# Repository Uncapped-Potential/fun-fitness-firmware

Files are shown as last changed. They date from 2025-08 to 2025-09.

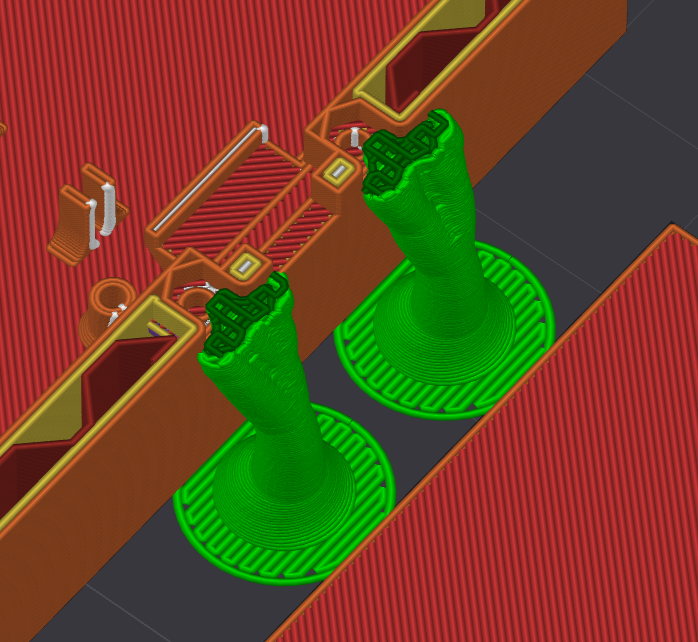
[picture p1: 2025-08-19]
enclosure_3D_models/print orientation photos and settings/cross section - not full depth supports.png

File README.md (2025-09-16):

# Fun Fitness Firmware

Production-ready ESP32-C3 firmware for the Fun Fitness wireless game controller with high-performance motion tracking and OTA update support.

## 🚀 Production Firmware

**Main firmware location**: [`codecell-firmware-minimal/`](./codecell-firmware-minimal/)

This is the production-ready firmware with:
- **60Hz Performance** - A:60Hz G:60Hz Q:20-40Hz BLE:60Hz streaming
- **Modular Architecture** - Clean separation with IMU manager and OTA worker
- **OTA Ready** - Complete over-the-air update implementation
- **Real Battery Status** - Proper USB/charging detection for OTA authorization

## Features

- **9-axis IMU** - Real-time motion tracking (accelerometer, gyroscope, rotation, magnetometer)
- **BLE Communication** - 60Hz quaternion streaming with 19-byte binary protocol
- **Motion Detection** - Configurable threshold with LED feedback
- **Power Management** - Vendor-compliant sleep/wake with motion-based activation
- **OTA Updates** - Queue-based firmware updates with CRC32 validation

## Hardware

- **Board**: CodeCell ESP32-C3
- **Sensors**: Built-in 9-axis IMU with magnetometer
- **Communication**: Bluetooth Low Energy (BLE)
- **Power**: Battery with USB charging

## 📁 Repository Structure

- **[`codecell-firmware-minimal/`](./codecell-firmware-minimal/)** - Production firmware (USE THIS)
- **[`archive/`](./archive/)** - Previous firmware experiments and troubleshooting docs
- **[`enclosure_3D_models/`](./enclosure_3D_models/)** - 3D printable enclosure files

## 🏗️ Development History

All previous firmware experiments have been archived to keep the repository clean. The current production firmware represents the culmination of extensive performance optimization and feature development, achieving reliable 60Hz streaming performance with proper power management.

## Bill of Materials (BOM)

### Core Components

1. **CodeCell Light + Motion (170mAh battery)**
   - Product: [CodeCell from Microbots.io](https://microbots.io/products/codecell)
   - Variant: Light + Motion / 170mAh 20C LiPo / Unsoldered
   - Specifications:
     - ESP32-C3 32-bit RISC-V (160 MHz)
     - BNO085 9-axis IMU (accelerometer, gyroscope, magnetometer)
     - VCNL4040 light/proximity sensor
     - 170mAh LiPo battery included
     - Dimensions: 18.5 x 18.5 x 9.4 mm
   - Included: 4x M1.2 self-tapping screws (~5mm) for mounting

2. **Power Switch**
   - Product: [SPDT Mini Slide Switch](https://www.amazon.com/dp/B0DN69PJ43)
   - Specifications:
     - Model: SS12D00G
     - Size: 8.7 x 3.7 x 11.7mm (L x W x H)
     - Pin Pitch: 0.1" / 2.54mm
     - Type: SPDT on-off, 3 pins
     - Mounting: Vertical through-hole, panel mount
     - Sliding knob length: 3mm
   - Quantity needed: 1

### Connectors and Cables

3. **JST 1.25mm Connectors**
   - Product: [JST 1.25mm 2-Pin Male/Female Cables](https://www.amazon.com/dp/B013JRWCBU)
   - Use: Battery connection
   - Quantity needed: 1 male-female pair

4. **USB-C Cable**
   - Product: [USB-C to USB-C Cable](https://www.amazon.com/dp/B0CGNK4LTT) (or any USB-C cable)
   - Use: Programming and charging
   - Quantity needed: 1

### Mounting Hardware

5. **M1.2 x 0.25mm Screws** (Current Option)
   - Product: [Laptop Screw Set](https://www.amazon.com/dp/B0D8PMBPB7)
   - Specifications: M1.2 x 0.25mm thread pitch, 4-6mm length
   - Quantity needed: 2 screws (from set)
   - Note: Currently tested and supported

6. **M1.2 x 0.25mm Nuts** (Current Option)
   - Product: [Stainless Steel Screw Set](https://www.amazon.com/dp/B0DBHNJLTD)
   - Specifications: M1.2 x 0.25mm thread pitch
   - Quantity needed: 2 nuts (from set)
   - Note: Must be press-fit into enclosure holes

**Alternative Hardware (Future - Testing in Progress):**
- **Screws**: [M1.2 x 5mm Individual Screws](https://www.amazon.com/dp/B0C1S9GHVB) - Specific size option
- **Nuts**: [M1.2 Hex Nuts](https://www.amazon.com/dp/B01N8UF3HU) - Individual nuts
- Note: These alternatives are being tested but not yet fully validated

7. **Mounting Adhesive**
   - Product: [Command Strips Velcro](https://www.amazon.com/dp/B0B3SR5M71) or any adhesive velcro
   - Use: Mounting controller to surfaces
   - Quantity needed: As required

### 3D Printed Enclosure

8. **Enclosure Components** (see `/enclosure_3D_models` directory)
   - **Files**: 
     - Up_FF_Body_V9_Rev_4.3mf (Body)
     - UP_FF_Lid_V9_Rev_4.3mf (Lid)
   - **Material**: **FIRE RETARDANT (PC-FR) REQUIRED** for production use
   - **Quantity**: 1 of each component
   - **Format**: 3MF files provided, Bambu print profile available (may need adjustment for Prusa A1)
   - **Note**: Standard materials acceptable for internal testing only

#### Print Settings
   - **Layer Height**: 0.12mm
   - **Infill**: 15%
   - **Wall Loops**: 2
   - **Supports**: Minimal - CRITICAL: Only add supports to outer perimeter of holes
   - **Orientation**: See photos in `/enclosure_3D_models/print orientation photos and settings/`
   - **Important**: Do NOT add supports inside tight holes as they will be impossible to remove
   - Refer to photos for detailed print settings and support placement
   - Contact Cooper if you have any questions or problems

### Safety Equipment

9. **LiPo Safety Bag**
   - Product: [PAWBOSE Fireproof LiPo Battery Bag](https://www.amazon.com/PAWBOSE-Fireproof-185x75x60mm-Explosionproof-Protection/dp/B0F6LP63HD/)
   - Specifications: 185x75x60mm fireproof/explosionproof case
   - Use: Safe storage and charging of controller
   - **HIGHLY RECOMMENDED** for any LiPo battery use

### Assembly Instructions

1. **Prepare the Enclosure**
   - Press-fit the two M1.2 x 0.25mm nuts into the designated holes in the body
   - Ensure nuts are seated properly for threading

2. **Install CodeCell**
   - Insert the CodeCell into the body
   - Secure with the 4x M1.2 self-tapping screws that come with the CodeCell

3. **Assemble Switch Harness**
   - Connect the power switch inline with battery using JST connectors
   - (Additional switch harness specifications to be added)

4. **Install Battery**
   - Cut a small piece of adhesive velcro
   - Apply velcro to designated area in enclosure (see photos)
   - Apply matching velcro to battery
   - Press battery firmly into place
   - Ensure secure attachment with reasonable amount of velcro

5. **Cable Management**
   - Route JST connectors and cables through cable routing clips
   - Ensure all connections are secure
   - Verify nothing interferes with lid closure

6. **Final Assembly**
   - Perform shake test - everything should be secure
   - Align lid with body
   - Insert M1.2 x 0.25mm screws (4-6mm length) through lid into press-fit nuts
   - Tighten screws carefully - do not overtighten

### Safety Notes

- **Battery Inspection**: CRITICAL - Thoroughly inspect battery for any damage before installation
- **Lid Closure**: Ensure nothing is pressing on the battery when closing lid (risk of damage)
- **Velcro Attachment**: Battery must be properly secured with adequate velcro to prevent movement
- **Quality Control**: Additional QC specifications forthcoming
- **Fire Safety**: Always use fire retardant materials for enclosure in production
- **Storage**: Store and charge controller in LiPo safety bag
- **Handling**: Use proper ESD precautions when handling electronics
- Total assembled weight: ~8g (3.4g board + 4.6g battery)

## Quick Order BOM

For easy procurement, here's a table with links and quantities needed for **one FitChip assembly**:

| Component | Link | Qty |
|---|---|-----|
| CodeCell Light+Motion (170mAh) | [Microbots](https://microbots.io/products/codecell) | 1 |
| SPDT Slide Switch | [Amazon B0DN69PJ43](https://www.amazon.com/dp/B0DN69PJ43) | 1 |
| JST 1.25mm Male/Female Cables | [Amazon B013JRWCBU](https://www.amazon.com/dp/B013JRWCBU) | 1 pair |
| M1.2 x 0.25mm Screws (4-6mm) | [Amazon B0D8PMBPB7](https://www.amazon.com/dp/B0D8PMBPB7) | 2 from set |
| M1.2 x 0.25mm Nuts | [Amazon B0DBHNJLTD](https://www.amazon.com/dp/B0DBHNJLTD) | 2 from set |
| USB-C Cable | [Amazon B0CGNK4LTT](https://www.amazon.com/dp/B0CGNK4LTT) | 1 |
| Adhesive Velcro | [Amazon B0B3SR5M71](https://www.amazon.com/dp/B0B3SR5M71) | As needed |
| **Safety Equipment** | | |
| LiPo Safety Bag | [Amazon B0F6LP63HD](https://www.amazon.com/PAWBOSE-Fireproof-185x75x60mm-Explosionproof-Protection/dp/B0F6LP63HD/) | 1 |

## Required Tools & Materials

| Tool/Material | Purpose | Source |
|---|---|---|
| **3D Printer** | Print enclosure components | Required |
| **Fire Retardant Filament (PC-FR)** | Enclosure printing | [Bambu Lab PC-FR](https://us.store.bambulab.com/products/pc-fr) |
| **Soldering Iron** | Wire connections | Required |
| **Heat Gun** | Heat shrink application | Required |
| **Heat Shrink Tubing** | Wire insulation | Required |
| **Tweezers** | Component handling | Required |

**3D Print Files:** See `/enclosure_3D_models` directory - **fire retardant material required for production**
**Print Settings Photos:** See `/enclosure_3D_models/print orientation photos and settings/` for detailed guidance

## Data Protocol

The firmware supports two streaming formats for backward compatibility:

### Binary Protocol (Default - 19 bytes)

Compact binary format for efficient data transmission:

```
Byte Layout:
[0-1]   Roll (int16_t)      - Range: ±327°,     Scale: 0.01°
[2-3]   Pitch (int16_t)     - Range: ±327°,     Scale: 0.01°
[4-5]   Yaw (int16_t)       - Range: ±327°,     Scale: 0.01°
[6-7]   Accel X (int16_t)   - Range: ±65.5g,    Scale: 0.002g
[8-9]   Accel Y (int16_t)   - Range: ±65.5g,    Scale: 0.002g
[10-11] Accel Z (int16_t)   - Range: ±65.5g,    Scale: 0.002g
[12-13] Gyro X (int16_t)    - Range: ±3276°/s,  Scale: 0.1°/s
[14-15] Gyro Y (int16_t)    - Range: ±3276°/s,  Scale: 0.1°/s
[16-17] Gyro Z (int16_t)    - Range: ±3276°/s,  Scale: 0.1°/s
[18]    Battery (uint8_t)   - Range: 0-255,     Direct mapping
```

### Text Protocol (Legacy - ~85 bytes)

CSV format for older web app versions:

```
R:45.123,P:-12.456,Y:180.789,AX:0.123,AY:-0.456,AZ:9.789,GX:1.234,GY:-2.345,GZ:0.567,B:85
```

- **R**: Roll (degrees)
- **P**: Pitch (degrees)
- **Y**: Yaw (degrees)
- **AX/AY/AZ**: Accelerometer X/Y/Z (g-force)
- **GX/GY/GZ**: Gyroscope X/Y/Z (deg/s)
- **B**: Battery level (1-100%, 101=charging, 102=USB power)

## LED Indicators

- **Green** (≥80%): Good battery
- **Yellow** (50-79%): Medium battery
- **Orange** (20-49%): Low battery
- **Red blink** (<20%): Critical battery
- **Green breathing**: Charging

## Development Setup

### Prerequisites

- **Arduino IDE** - Download from [arduino.cc](https://www.arduino.cc/en/software)
- **macOS** - May require Xcode and newest macOS version
- **USB Driver** - For ESP32 serial communication

### Installation

1. Download and install Arduino IDE
2. Clone this repository:
   ```bash
   git clone https://github.com/Uncapped-Potential/fun-fitness-firmware.git
   cd fun-fitness-firmware
   ```
3. Open `codecell-firmware/codecell-firmware.ino` in Arduino IDE (must have nested folder and file with same name, quirk of arduino)

### Guide [Video](https://drive.google.com/file/d/13qVB6rGZdJrtGnBQS_VcSYYFrTN_345D/view?usp=vids_web) 

### Board Configuration

1. In Arduino IDE, go to **Tools > Board > Boards Manager**
2. Search for "ESP32" and install "esp32 by Espressif Systems"
3. Select **Tools > Board > ESP32 Arduino > ESP32C3 Dev Module**

### Required Libraries

Install via **Tools > Manage Libraries**:
- **CodeCell** - For CodeCell hardware support

**Note**: ESP32 core support is installed via Boards Manager (see Board Configuration above), not Library Manager. BLE support is included with the ESP32 core.

### Upload

1. Connect CodeCell via USB
2. Select correct port in **Tools > Port**
3. Click Upload button or press Cmd+U

## Configuration

- **Data rate**: 24Hz (optimized from 50Hz for battery life)
- **Protocol**: Binary by default (19 bytes per packet)
- **BLE Service UUID**: `12345678-1234-1234-1234-123456789012`
- **BLE Characteristic UUID**: `dcba4330-dcba-4321-dcba-432123456791`

## Performance & Optimization

### Binary Protocol Benefits

- **77% bandwidth reduction**: 19 bytes vs ~85 bytes per packet
- **Lower power consumption**: Less data to transmit over BLE
- **Higher precision**: Fixed-point encoding preserves accuracy
- **Future-proof**: Supports high g-force gaming movements (±65.5g)

### Protocol Selection

The web application automatically detects the protocol format using content-based analysis:
- Binary data: 19-byte packets with specific structure
- Text data: Contains pattern "R:...P:...Y:..."

No firmware changes needed - the web app handles both formats seamlessly.

## Troubleshooting

- **Upload fails**: Ensure you have selected ESP32C3 Dev Module and correct port
- **Libraries not found**: Install via Library Manager, not manual download
- **macOS permissions**: May need to allow Arduino IDE in Security & Privacy settings
- **High g-force readings**: Binary protocol supports up to ±65.5g for vigorous gaming
- **Battery drain**: Reduced polling to 24Hz and binary protocol optimize battery life
- **Device name shows old name in Chrome**: Chrome Web Bluetooth caches device names persistently. After updating firmware device name, Chrome may still show the old name. Solutions:
  - Use a different browser (Safari, Firefox) 
  - Restart Chrome completely
  - Use Chrome Incognito mode
  - Connect with a different device/computer
  - Note: This is a browser caching issue, not a firmware problem
- **Upload errors "chip stopped responding"**: If you get upload failures after potential pin shorting:
  1. Try uploading again (may work on retry)
  2. If persistent, erase flash: `esptool --port /dev/cu.usbmodem1101 erase_flash`
  3. Then upload firmware normally through Arduino IDE
  4. Device should recover and show "New connection established" in serial monitor

## Known Issues

- **Sleep Mode**: Motion-based wake not yet implemented (Issue #6)
- **IMU Overflow**: Data may overflow after ~10 minutes of continuous use
- **LED Conflicts**: Some LED library conflicts may occur with certain CodeCell versions

See [GitHub Issues](https://github.com/Uncapped-Potential/fun-fitness-firmware/issues) for bug reports and feature requests.

## Changelog

### v2.0.0 (Current)
- Added binary protocol (77% size reduction)
- Reduced polling rate to 24Hz for battery optimization
- Increased acceleration range to ±65.5g for gaming
- Added magnetometer support
- Improved battery level reporting at 24Hz

### v1.0.0
- Initial release with text-based CSV protocol
- 50Hz IMU streaming
- Battery monitoring with LED indicators
- Auto-reconnect support

## Related Projects

- [fun-fitness-web](https://github.com/Uncapped-Potential/fun-fitness-web) - Web application that receives controller data

## License

[Add your license here]

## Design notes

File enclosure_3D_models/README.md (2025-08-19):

# Fun Fitness Controller Enclosure

3D printable case files for the Fun Fitness wireless game controller.

## Print Files

### Current Version Components (1 each)

1. **Up_FF_Body_V9_Rev_4.3mf** - Main controller body
2. **UP_FF_Lid_V9_Rev_4.3mf** - Top cover/lid

### Legacy Version (in Old/ folder)
- Up V7 Body - PC-FR Rev 2.obj
- Up V7 lid - PC-FRrev2.obj  
- Up V7 switch cradle - PC-FR Rev 3.obj

### Material Requirements

**⚠️ FIRE RETARDANT MATERIAL REQUIRED**

For any use beyond internal testing, all components **MUST** be printed in fire retardant (PC-FR) material:

- **Recommended Material**: Polycarbonate Fire Retardant (PC-FR)
- **Reason**: Contains 170mAh LiPo battery - fire safety is critical
- **Internal Testing**: Standard materials acceptable for prototyping only

### Print Settings

- **Layer Height**: 0.12mm
- **Infill**: 15%
- **Wall Loops**: 2
- **Supports**: Minimal - **CRITICAL**: Only add supports to outer perimeter of holes
  - Do NOT add supports inside tight holes (impossible to remove)
  - See photos in `print orientation photos and settings/` folder for detailed guidance
- **Print Orientation**: Optimal orientation shown in photos
- **Note**: Bambu print profile available (may need adjustment for Prusa A1)

For detailed print settings and support placement, refer to the photos in the `print orientation photos and settings/` directory. Contact Cooper if you have any questions or problems.

### Assembly Instructions

1. **Prepare the Enclosure**
   - Press-fit two M1.2 x 0.25mm nuts into designated holes in the body
   - Ensure nuts are seated properly for threading

2. **Install CodeCell**
   - Insert CodeCell into the body
   - Secure with 4x M1.2 self-tapping screws (included with CodeCell)

3. **Assemble Switch Harness**
   - Connect power switch inline with battery using JST connectors
   - (Additional switch harness specifications to be added)

4. **Install Battery**
   - Cut small piece of adhesive velcro
   - Apply velcro to designated area in enclosure (see photos)
   - Apply matching velcro to battery
   - Press battery firmly into place
   - Ensure secure attachment with reasonable amount of velcro

5. **Cable Management**
   - Route JST connectors and cables through cable routing clips
   - Ensure all connections are secure
   - Verify nothing interferes with lid closure

6. **Final Assembly**
   - Perform shake test - everything should be secure
   - Align lid with body
   - Insert M1.2 x 0.25mm screws (4-6mm length) through lid into press-fit nuts
   - Tighten screws carefully - do not overtighten

### Required Hardware

- **2x M1.2 x 0.25mm screws** (4-6mm length) - [Amazon B0D8PMBPB7](https://www.amazon.com/dp/B0D8PMBPB7)
- **2x M1.2 x 0.25mm nuts** - [Amazon B0DBHNJLTD](https://www.amazon.com/dp/B0DBHNJLTD)
- **4x M1.2 self-tapping screws** (included with CodeCell)
- **Adhesive velcro** for battery mounting

### Safety Notes

- **Battery Inspection**: CRITICAL - Thoroughly inspect battery for any damage before installation
- **Lid Closure**: Ensure nothing is pressing on the battery when closing lid (risk of damage)
- **Velcro Attachment**: Battery must be properly secured with adequate velcro to prevent movement
- **Fire Safety**: Use fire retardant materials for production builds
- **Storage**: Store and charge in LiPo safety bag (see main README)
- **Ventilation**: Ensure proper ventilation around device during charging
- **Inspection**: Check enclosure for cracks or damage before each use
- **Quality Control**: Additional QC specifications forthcoming
- **Handling**: Use proper ESD precautions when handling electronics

## File Format

Files are provided in 3MF format with embedded print settings. The 3MF format is compatible with most modern 3D printing software including:

- Bambu Studio (native support)
- PrusaSlicer 
- Cura
- Other slicers supporting 3MF import

Legacy OBJ files with MTL material definitions are available in the Old/ folder for compatibility with older software.

## Support Resources

- **Print Settings Photos**: See `print orientation photos and settings/` folder
- **Questions/Problems**: Contact Cooper for assistance
- **Main Documentation**: See parent directory README for complete BOM and specifications

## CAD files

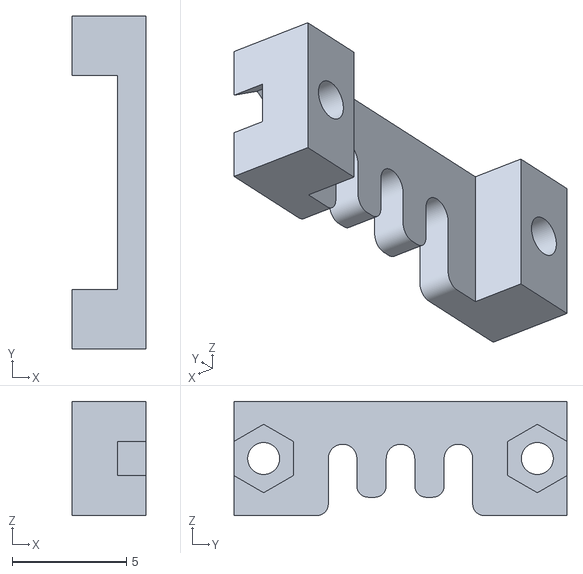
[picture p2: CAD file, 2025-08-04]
enclosure/Up V7 switch cradle - PC-FR Rev 3.obj
3.25 x 14.6 x 5.00

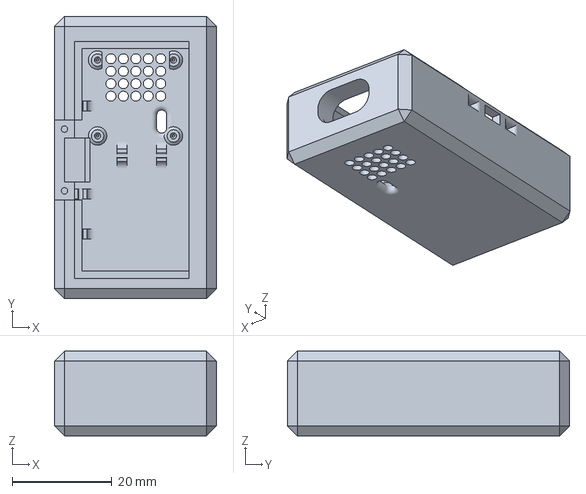
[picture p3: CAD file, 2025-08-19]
enclosure_3D_models/Up_FF_Body_V9_Rev_4.3mf
32.5 x 56.6 x 17.0 mm

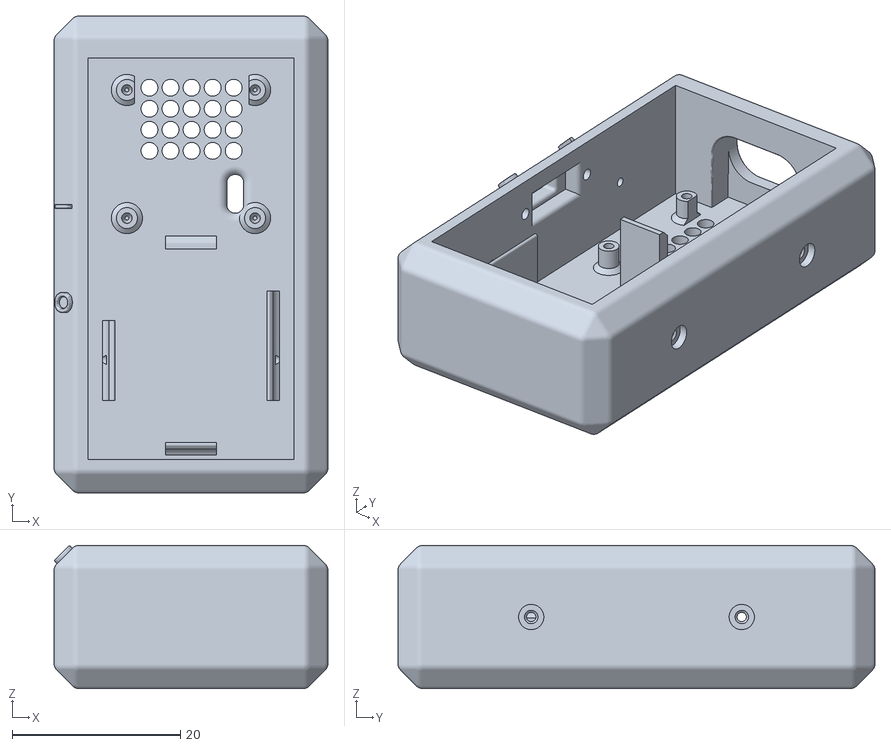
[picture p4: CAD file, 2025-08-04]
enclosure/Up V7 Body - PC-FR Rev 2.obj
32.5 x 56.6 x 17.0

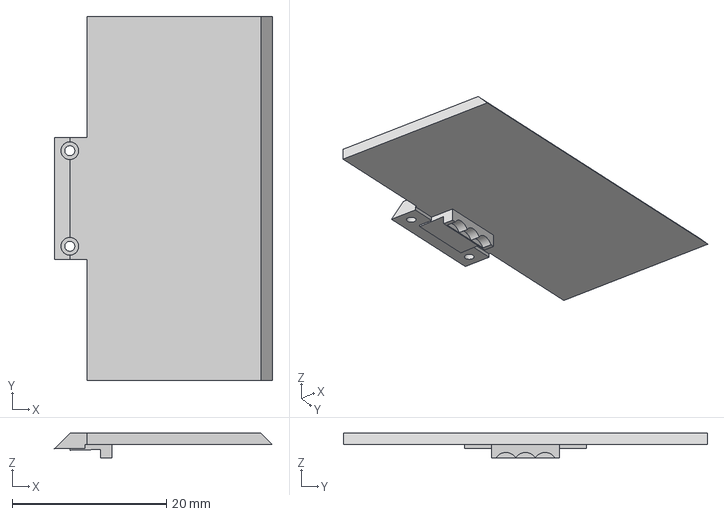
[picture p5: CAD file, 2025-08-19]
enclosure_3D_models/UP_FF_Lid_V9_Rev_4.3mf
28.3 x 47.2 x 3.20 mm

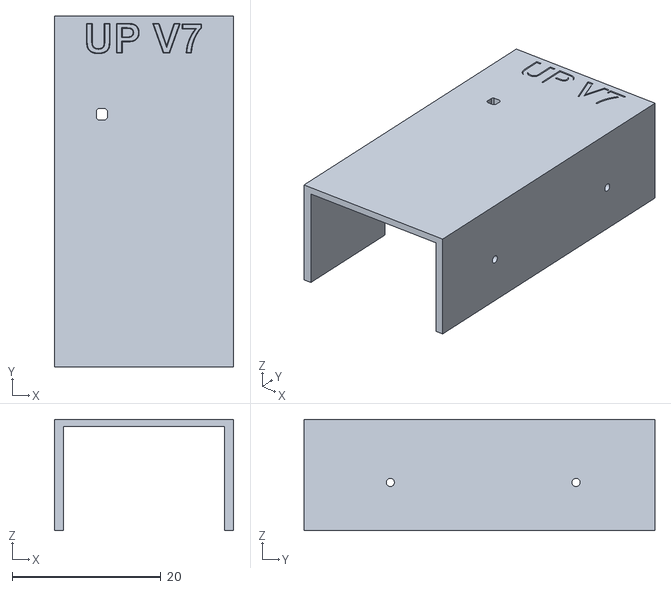
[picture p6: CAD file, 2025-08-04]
enclosure/Up V7 lid - PC-FRrev2.obj
24.1 x 47.2 x 15.0

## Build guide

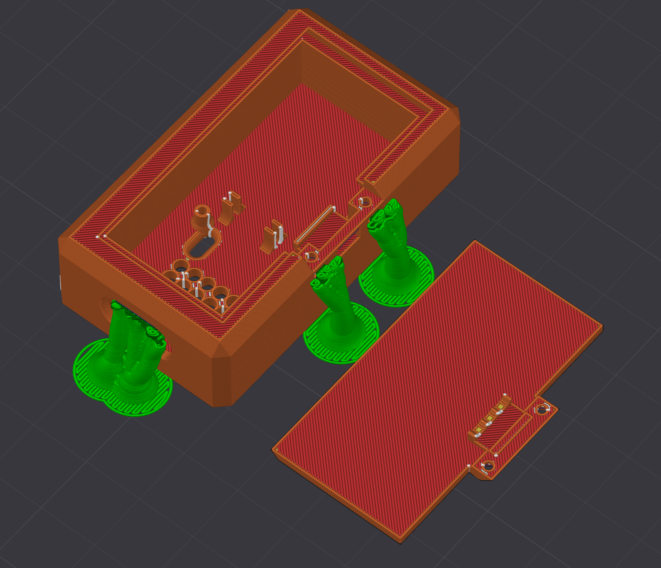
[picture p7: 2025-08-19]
enclosure_3D_models/print orientation photos and settings/supports 2.png

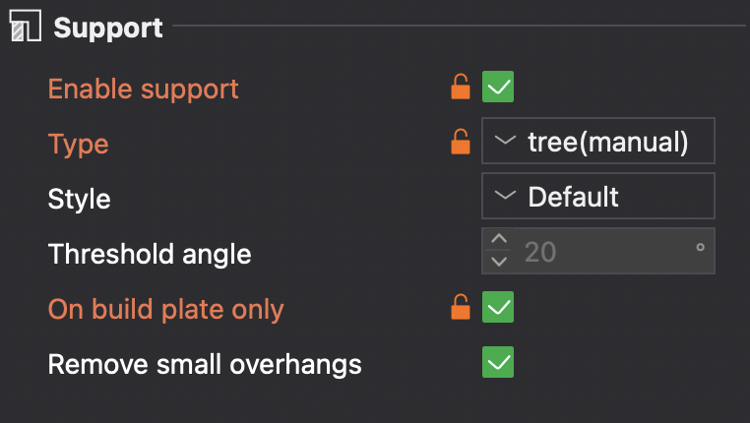
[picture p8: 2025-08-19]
enclosure_3D_models/print orientation photos and settings/print settings (supports) .png

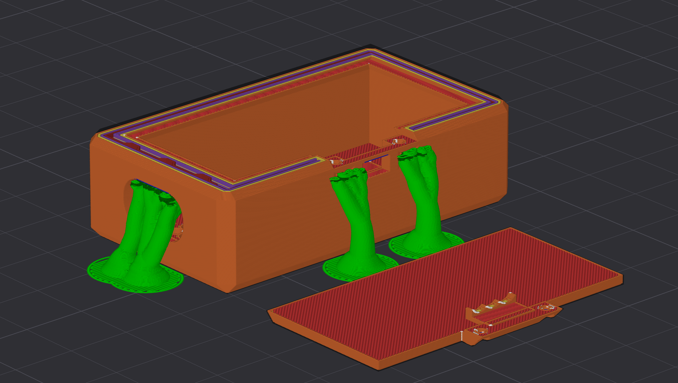
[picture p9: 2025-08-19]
enclosure_3D_models/print orientation photos and settings/supports.png

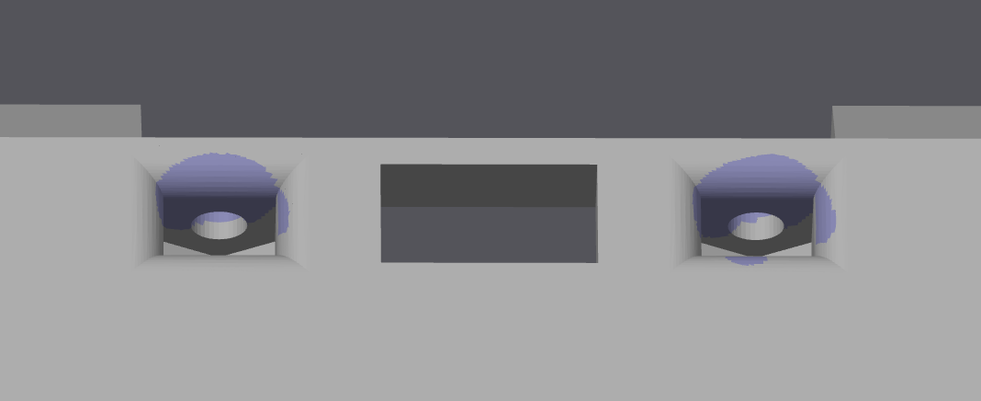
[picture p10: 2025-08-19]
enclosure_3D_models/print orientation photos and settings/m1pt2 by pt25 nut supports.png

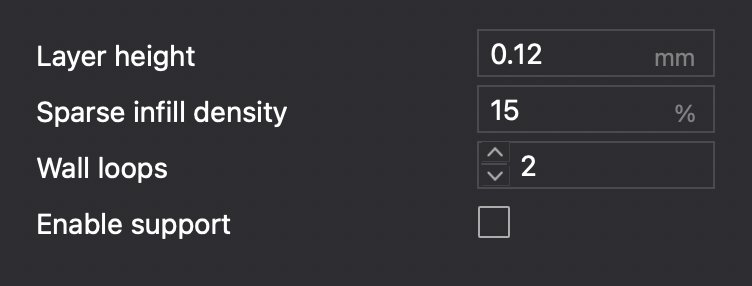
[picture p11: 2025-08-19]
enclosure_3D_models/print orientation photos and settings/print settings 1.png

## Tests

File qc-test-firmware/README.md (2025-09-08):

# CodeCell QC Test System

Complete charge controller safety testing system for BQ24232RGTR hardware validation.

## Overview

This QC system tests the critical safety functions of the charge controller IC to prevent battery overcharging. It runs comprehensive charge/discharge cycles while logging all parameters via Bluetooth.

## Hardware Requirements

- **Charge IC**: BQ24232RGTR (U5)
- **Pin Connections**:
  - CE (Charge Enable) → GPIO 10
  - PGOOD (Power Good) → GPIO 18  
  - CHG (Charge Status) → GPIO 8
  - VBAT (Battery ADC) → GPIO 1
- **Battery**: 170mAh LiPo (3.0V - 4.2V)
- **Thermal Camera**: For temperature monitoring
- **USB Hub**: 12-port hub for parallel testing

## Files

1. **`qc-test-firmware.ino`** - Arduino firmware for QC testing
2. **`QC_Test_Parallel.ipynb`** - Jupyter notebook for parallel testing
3. **`requirements.txt`** - Python dependencies
4. **`README.md`** - This file

## Quick Start

### 1. Flash QC Firmware
```bash
# Open Arduino IDE
# Load qc-test-firmware.ino
# Select ESP32-C3 board
# Flash to each device via USB
```

### 2. Install Python Dependencies
```bash
pip install -r requirements.txt
```

### 3. Run QC Test
```bash
jupyter notebook QC_Test_Parallel.ipynb
```

## Test Procedure

### Complete Test (6-8 Hours)
1. **Initial State Check** (5 min)
   - Verify PGOOD=0 (USB connected)
   - Verify CHG=1 (not charging)
   - Battery voltage 3.0-4.2V

2. **2-Hour Charge Cycle**
   - Enable charging (CE=LOW)
   - Monitor voltage increase
   - Log at 0.5Hz

3. **2-Hour Discharge** 
   - Unplug USB hub
   - Monitor voltage decrease
   - Log at 0.5Hz

4. **15-Minute Charge Intervals**
   - Repeat until battery full
   - Plug/unplug between cycles

5. **Final 2-Hour Discharge**
   - High-frequency logging (60Hz)
   - Simulate heavy use

### Quick Test (2 Minutes)
For debugging and validation:
```python
# In Jupyter notebook
await quick_test()
```

## Safety Features

⚠️ **SAFE MODE ENABLED** - GPIO pins disabled until schematic verification

- **Thermal Monitoring**: 50°C threshold via thermal camera
- **Battery Protection**: 3.0V-4.2V range via CodeCell library  
- **Charge Control**: ~~Direct CE pin control~~ **DISABLED FOR SAFETY**
- **USB Detection**: ~~PGOOD pin monitoring~~ **Estimated from voltage**
- **Emergency Stop**: Manual intervention capability

## Communication Protocol

### BLE Services
- **Service**: `8f20d6c8-5f7d-4e7b-9b1c-0a701c3a2000`
- **Command**: `8f20d6c8-5f7d-4e7b-9b1c-0a701c3a2001` (WRITE)
- **Status**: `8f20d6c8-5f7d-4e7b-9b1c-0a701c3a2002` (READ/notify)
- **Log**: `8f20d6c8-5f7d-4e7b-9b1c-0a701c3a2003` (notify)

### Commands (Safe Mode)
```cpp
QC_GET_STATUS = 0x01     // Get current status (voltage + temp only)
// QC_CHARGE_ENABLE = 0x02  // DISABLED FOR SAFETY
// QC_CHARGE_DISABLE = 0x03 // DISABLED FOR SAFETY  
QC_START_LOGGING = 0x05  // Start phase logging
QC_CHECKPOINT = 0x07     // Mark checkpoint
QC_SELF_TEST = 0x09      // Run safe self-test (no GPIO)
```

## Results

Test generates CSV reports with format:
```csv
device_name,serial,address,final_battery_mv,connection,initial_state,charge_2h,discharge_2h,final_result
QC_001,1,AA:BB:CC:DD:EE:01,3850,PASS,PASS,PASS,PASS,PASS
QC_002,2,AA:BB:CC:DD:EE:02,3780,PASS,PASS,PASS,FAIL,FAIL
```

## Troubleshooting

### No Devices Found
- Check firmware is flashed correctly
- Verify devices are powered via USB
- Ensure Bluetooth is enabled on computer

### Connection Fails  
- Restart devices
- Check BLE service UUIDs match
- Reduce number of parallel connections

### Test Fails
- Check GPIO pin connections
- Verify battery is connected
- Monitor thermal camera for overheating
- Check USB hub power capacity

### Thermal Issues
- Ensure adequate ventilation
- Check for short circuits
- Verify charge current (should be ~90mA)
- Stop test if temperature >50°C

## Manufacturing Integration

1. **Batch Testing**: Test 12 boards simultaneously
2. **Serial Tracking**: Device names include 3-digit serials (001, 002, etc.)
3. **Pass/Fail Marking**: Apply QC stickers to PASS units only
4. **Report Archive**: Save CSV reports with timestamps
5. **Production Firmware**: Flash production firmware on PASS units

## Technical Notes

- **Charge Current**: ~90mA (set by R12=10kΩ resistor)
- **Battery Chemistry**: LiPo with 170mAh capacity
- **Test Coverage**: Charge enable/disable, power good detection, voltage monitoring
- **Data Integrity**: All critical measurements logged with timestamps
- **Parallel Capability**: Python asyncio handles up to 12 concurrent BLE connections

This system ensures charge controller hardware safety before production firmware deployment.

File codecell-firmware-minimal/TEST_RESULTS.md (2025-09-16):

# OTA Implementation Test Results

## ✅ Configuration Tests

### OTA Constants Defined
```cpp
#define OTA_CHUNK_SIZE          128     // Conservative chunk size (bytes)
#define OTA_QUEUE_SIZE          8       // FreeRTOS queue depth
#define OTA_TASK_STACK_SIZE     4096    // Stack size for OTA worker task
#define OTA_TASK_PRIORITY       1       // Low priority (below main loop)
#define OTA_CHUNK_TIMEOUT_MS    30000   // 30-second chunk timeout
#define OTA_SESSION_TIMEOUT_MS  300000  // 5-minute session timeout
```
**Status**: ✅ PASS - All OTA constants properly defined

### Quaternion W Sign Implementation
```cpp
uint8_t wSign = (qr >= 0) ? 0x80 : 0x00;  // Bit 7: 1=positive W, 0=negative W
binaryData[18] = (batteryLevel & 0x7F) | wSign; // Battery in bits 0-6, W sign in bit 7
```
**Status**: ✅ PASS - W sign properly packed into battery byte bit 7

### BLE Service Architecture
```
Single Service: 12345678-1234-1234-1234-123456789012
├── Quaternion: dcba4330-dcba-4321-dcba-432123456791 (NOTIFY) - 60Hz streaming
└── OTA Control: 8f20d6c8-5f7d-4e7b-9b1c-0a701c3a0002 (WRITE/NOTIFY) - All OTA commands
```
**Status**: ✅ PASS - Single service with 2 characteristics (unified OTA protocol)

## ✅ Code Integration Tests

### OTA Worker Integration
- ✅ OTA worker included and initialized
- ✅ Error handling with LED feedback
- ✅ Proper initialization order

### OTA Protocol Callbacks
- ✅ OP_START (0x01) → ACK (0xa1) - 11-byte command with little-endian parsing
- ✅ OP_DATA (0x02) → Offset-based chunk processing via same characteristic
- ✅ OP_FINISH (0x03) → ACK (0xa2)
- ✅ Comprehensive logging with hex dumps for debugging

### Performance Protection
- ✅ Sleep protection during OTA operations
- ✅ OTA status monitoring in debug output
- ✅ Queue-based processing (no heavy work in BLE callbacks)

## 🧪 Ready for Testing

### Expected Behavior on Upload:
1. **Serial Output**:
   ```
   CodeCell Minimal Motion Detection
   Phase 3: Adding BLE Streaming
   Initializing motion sensors...
   IMU manager initialization complete
   OTA worker initialization complete
   Initializing BLE...
   BLE initialization complete - advertising started
   ```

2. **60Hz Performance**:
   ```
   [1s] Rates: A:60.0Hz G:60.0Hz Q:20-40Hz BLE:60.0Hz | Quat:[x,y,z,w] valid:YES | BLE:Conn | Heap:XXXk
   ```

3. **W Sign in Battery**:
   - Battery values 0-127 (bits 0-6)
   - W sign in bit 7 (0x80 = positive, 0x00 = negative)
   - Special values: 101 (charging), 102 (USB only) - bit 7 preserved

### Web App OTA Testing:
1. **Connect to device** - should find single service with 2 characteristics
2. **Subscribe to OTA Control notifications** for ACK responses
3. **Send OP_START command** (11 bytes) - should receive ACK 0xa1 immediately
4. **Send firmware chunks** via OTA Control characteristic with OP_DATA (0x02)
5. **Send OP_FINISH command** - should receive final ACK 0xa2
6. **Device should restart** with new firmware

## 🎯 Test Commands

### Build and Upload:
```bash
# Arduino IDE: Open codecell-firmware-minimal.ino and upload
# OR use arduino-cli:
arduino-cli compile --fqbn esp32:esp32:esp32c3 .
arduino-cli upload --fqbn esp32:esp32:esp32c3 -p /dev/cu.usbmodem* .
```

### Serial Monitor:
```bash
# Monitor at 115200 baud for debug output
arduino-cli monitor -p /dev/cu.usbmodem* -c baudrate=115200
```

### Web App Testing:
- Device should appear as "FitChip011"
- Quaternion streaming should work at 60Hz
- OTA button should be enabled when USB powered (battery 101/102)
- Single OTA Control characteristic should handle all OTA communication
- Serial monitor should show hex dumps of received OTA commands

## 🚨 Troubleshooting

### If Compilation Fails:
- Check all OTA constants are defined in config.h
- Verify ota_worker.h/cpp files are present
- Check Arduino ESP32 core version (should be 3.x)

### If OTA Doesn't Work:
- Check serial output for OTA command reception
- Verify ACK responses are sent
- Monitor heap usage during OTA
- Check for timeout errors in web app

### If Performance Degrades:
- Monitor heap usage - should stay ~166k
- Check for excessive logging
- Verify 60Hz rates are maintained during OTA

**Status**: 🎯 **READY FOR PRODUCTION TESTING**

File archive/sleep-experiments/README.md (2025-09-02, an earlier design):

# Sleep Mode Experiments Archive

## Overview
This directory contains experimental implementations of sleep/wake functionality that were attempted but did not work as expected. These are preserved for reference and future debugging.

## Experiments Included

### 1. serial-test/
- **Purpose**: Basic serial communication test to debug why Serial output wasn't working on "Sara" chip
- **Result**: No serial output at any baud rate (115200, 9600, etc.)
- **Conclusion**: Possible hardware issue with specific CodeCell unit

### 2. proximity-sleep/
- **Purpose**: Official CodeCell sleep example using proximity sensor for wake detection
- **Source**: Based on CodeCell documentation example
- **Result**: LED control conflicts, couldn't verify sleep/wake behavior
- **Issue**: Underlying firmware appears to control LED, preventing debug feedback

### 3. BNO085 Motion State Implementation (in main firmware - reverted)
- **Purpose**: Use BNO085's built-in motion state detection for sleep/wake
- **Features**:
  - Motion states: On Table (1), Stationary (2), Stable (3), Motion (4)
  - 8-second sleep timeout for testing (90 seconds for production)
  - ESP32 light sleep with 1-second wake intervals
- **Result**: 
  - ✅ Successfully enters sleep after timeout
  - ❌ Never wakes on motion
  - ❌ BLE doesn't restart after wake
  - ❌ No serial debug output

## Key Findings

1. **Hardware Issues**: "Sara" chip appears to have non-functional serial, possibly damaged
2. **API Uncertainty**: CodeCell's `Sleep()` and `WakeUpCheck()` behavior unclear
3. **Motion Detection Works**: BNO085 motion state detection functions correctly when awake
4. **Sleep Entry Works**: Device successfully enters sleep mode
5. **Wake Mechanism Broken**: Once asleep, device doesn't properly wake on motion

## Technical Details

### Attempted Approaches:
1. **ESP32 Light Sleep**: Preserves RAM but device doesn't wake properly
2. **Delay-based Sleep**: Removed ESP32 sleep, used delays - still no wake
3. **Proximity Wake**: Official example, but couldn't verify due to LED conflicts

### Code Structure:
```cpp
// Key functions attempted:
checkSleepWakeState() - Monitor motion state and trigger sleep
enterLightSleep() - ESP32 light sleep with timer wake  
Motion_StateRead() - BNO085 built-in motion classification
```

## Recommendations for Future Attempts

1. **Test with Different Hardware**: Rule out "Sara" chip damage
2. **Contact Microbot Support**: Clarify Sleep/WakeUpCheck API behavior
3. **Start Simple**: Timer-only sleep without motion detection
4. **External Wake Source**: Consider button or interrupt-based wake
5. **Debug Without Serial**: Use LED patterns or BLE data for debugging

## Related Issues
- GitHub Issue #6: ESP32 Sleep Mode Implementation Causes Multiple Critical Failures
- GitHub Issue #1: Implement sleep mode with motion-based wake

## Note
The main firmware has been reverted to the working version without sleep functionality. All core features (BLE streaming, battery monitoring, auto-reconnect) work perfectly without sleep mode.

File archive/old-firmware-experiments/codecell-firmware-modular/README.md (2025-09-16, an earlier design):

# CodeCell Modular Firmware

Rebuilt firmware using Gall's Law - start with a simple working system and add complexity gradually.

## Arduino IDE Usage

**⚠️ Important**: Arduino IDE only allows one `.ino` file per directory.

### Main Firmware
- Open `codecell-firmware-modular.ino` in Arduino IDE
- This is the main production firmware

### Test Framework
- Open `test/test_compile/test_compile.ino` in Arduino IDE
- This tests compilation and module structure with mock data

## Project Structure

```
codecell-firmware-modular/
├── codecell-firmware-modular.ino    # Main sketch
├── config.h                         # Configuration constants
├── logger.h / logger.cpp            # Event logging system
├── imu_manager.h / imu_manager.cpp  # BNO085 with vendor patterns
├── ble_service.h / ble_service.cpp  # BLE GATT service
├── test/
│   └── test_compile/                # Test sketch directory
│       ├── test_compile.ino         # Test runner
│       └── [copied module files]    # Module copies for testing
└── README.md                        # This file
```

## Implementation Progress

### ✅ Phase 0: Scaffolding & Logging
- Event logging with levels (ERROR, WARN, INFO, DEBUG)
- Boot diagnostics (reset reason, partition, heap)
- Memory tracking

### ✅ Phase 1: IMU Manager
- Proper vendor patterns: single `Init()`, single `Run()` per loop
- Fusion-ready gating (wait for valid quaternions)
- Motion detection with delta calculation
- Test mode support for development

### 🚧 Phase 2: BLE Service (In Progress)
- GATT service with quaternion and config characteristics
- MTU logging and connection parameter tracking
- No heavy work in callbacks (queue-based design)

### ⏳ Phase 3: OTA Worker
- FreeRTOS queue for chunk processing
- Conservative 128-byte chunks with CRC validation
- Worker task pattern (no work in GATT callbacks)

### ⏳ Phase 4: Power Manager
- Vendor sleep/wake: `myCodeCell.Sleep(1)` and `WakeUpCheck()`
- State machine: ACTIVE → BLE_OFF → SLEEP
- Motion-based wake detection

## Key Design Decisions

1. **Vendor Pattern Compliance**
   - Single `myCodeCell.Init()` call in setup
   - Single `myCodeCell.Run()` call per loop iteration
   - Use vendor sleep/wake functions exclusively

2. **No Heavy Work in Callbacks**
   - BLE callbacks copy data to queues and return immediately
   - Worker tasks process queued data outside interrupt context

3. **Fusion-Ready Gating**
   - Never send quaternions until BNO085 fusion engine is ready
   - Wait for valid quaternion magnitude before enabling notifications

4. **Conservative OTA**
   - Start with 128-byte chunks (not 200)
   - CRC validation and rollback support
   - Timeout handling for incomplete transfers

## Testing Strategy

Each phase includes:
1. **Unit tests** with mocks (test_compile.ino)
2. **Integration test** when added to main sketch
3. **Stress testing** at completion

## Upload Instructions

1. **For main firmware**: Open `codecell-firmware-modular.ino` in Arduino IDE
2. **For testing**: Open `test/test_compile/test_compile.ino` in Arduino IDE
3. Select your ESP32-C3 board and upload
4. Monitor serial output at 115200 baud

## Expected Serial Output

```
=================================
CodeCell Modular Firmware v1.0
=================================
BOOT: Reset reason: Power-on
BOOT: Active partition: app0
BOOT: Free heap: 295000 bytes
INFO: === Phase 1 Testing ===
INFO: Device: FitChip011
INFO: Initializing IMU manager...
INFO: IMU stabilization delay (3000 ms)...
INFO: Full sensor suite initialization successful
INFO: Fusion engine ready!
INFO: IMU: quat=[x,y,z] accel=[x,y,z] motion=delta fusion=READY
```

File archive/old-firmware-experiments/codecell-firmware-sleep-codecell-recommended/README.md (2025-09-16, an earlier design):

# CodeCell Team Recommended Implementation

This firmware implements the CodeCell team's recommendations based on their feedback to address BNO085 sensor issues and improve power management.

## Key Changes Based on CodeCell Team Feedback

### 1. Proper Sleep/Wake Implementation
- **Uses `myCodeCell.Sleep(1)`** instead of custom ESP32 light sleep functions
- **Uses `myCodeCell.WakeUpCheck()`** for proper wake-up cause detection
- **Follows their motion alarm example** pattern for sleep/wake cycles

### 2. Correct Function Usage  
- **Single `myCodeCell.Run()` call** per loop iteration as recommended
- **Uses `myCodeCell.Init()` once** in setup for fresh boots
- **Uses `myCodeCell.Motion_Init()`** for wake-from-sleep scenarios

### 3. Proper Sensor Initialization Sequence
- **Follows their recommended pattern**: WakeUpCheck() → Motion_Init() → stabilization delay → motion check
- **Handles sensor fusion timing**: Longer delays for fusion algorithms as they noted
- **Proper reinitialization** after wake-up from sleep

### 4. Simplified Architecture
- **Single file implementation** (avoiding Arduino IDE compilation overhead we discovered)
- **Removed complex power state machine** in favor of their simpler sleep approach  
- **Eliminated custom ESP32 sleep functions** that could interfere with their peripheral management

## Comparison with Previous Implementation

| Aspect | Previous (Custom) | New (CodeCell Recommended) |
|---|---|---|
| Sleep Method | `esp_light_sleep_start()` | `myCodeCell.Sleep(1)` |
| Wake Detection | `esp_sleep_get_wakeup_cause()` | `myCodeCell.WakeUpCheck()` |
| Run() Calls | Multiple per loop | Single per loop |
| Initialization | Complex retry logic | Their recommended pattern |
| Power Management | Custom state machine | Simple motion-based sleep |

## Expected Benefits

1. **Proper Peripheral Management**: Their sleep function handles peripheral shutdown correctly
2. **Better Sensor Recovery**: Their wake-up pattern should maintain sensor state better  
3. **Simplified Logic**: Less complex code means fewer edge cases
4. **CodeCell Support**: Following their examples means better support/documentation

## Testing Priority

1. **Basic functionality** - Does it boot and stream data correctly?
2. **Sleep/wake cycles** - Does `myCodeCell.Sleep(1)` work reliably?
3. **Sensor persistence** - Do sensors maintain state across sleep cycles?
4. **Power cycle resilience** - Does it still need the 3-4 second power-off requirement?

## Potential Improvements Over Our Previous Solution

If this works as intended, it should:
- Eliminate the 3-4 second power cycle requirement completely
- Provide more reliable sensor state management
- Reduce overall code complexity
- Align with CodeCell's tested and supported patterns

This implementation directly addresses their feedback while maintaining all the essential functionality from our previous working version.

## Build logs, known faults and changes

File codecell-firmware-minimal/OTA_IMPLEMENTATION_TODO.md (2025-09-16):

# OTA Implementation TODO List

## Current Status ✅
- **Working firmware**: Single BLE service with 60Hz quaternion streaming
- **Working web app**: Connects and receives data successfully
- **OTA implementation**: Complete firmware-side implementation committed to git (`ab5036c`)

## What's Done ✅

### Firmware Side (Commit: ab5036c)
- ✅ Two-service BLE architecture (Data + OTA services)
- ✅ Queue-based OTA worker with FreeRTOS task
- ✅ Proper protocol acknowledgments (OP_START → 0xa1, OP_FINISH → 0xa2)
- ✅ CRC32 validation and timeout handling
- ✅ Conservative 128-byte chunks
- ✅ Real battery status reporting (101=charging, 102=USB only)
- ✅ Service UUIDs match web app expectations

### Web App Side
- ✅ Data service connection and streaming
- ✅ Battery status detection for OTA authorization
- ✅ OTA service UUID discovery working

## What Needs to be Finished 🚧

### Web App OTA Integration

#### 1. Fix Data Transmission Issue
**Problem**: After adding OTA service, data transmission stopped working
**Root Cause**: Web app likely has connection issues with two-service architecture

**Solutions to Try**:
- [ ] **Option A**: Keep current single-service firmware, add OTA as second characteristic
- [ ] **Option B**: Debug why two-service version breaks data connection
- [ ] **Option C**: Add connection retry logic in web app

#### 2. Complete OTA Protocol Implementation
**Current State**: Web app finds OTA service but times out waiting for acknowledgments

**Required Web App Changes**:
- [ ] **Subscribe to OTA control characteristic notifications**
  ```javascript
  await otaControlChar.startNotifications();
  otaControlChar.addEventListener('characteristicvaluechanged', handleOtaAck);
  ```

- [ ] **Implement proper OP_START protocol**
  ```javascript
  // Send: [0x01][length_low][length_mid][length_high]
  const startCmd = new Uint8Array([0x01, size & 0xFF, (size >> 8) & 0xFF, (size >> 16) & 0xFF]);
  await otaControlChar.writeValue(startCmd);
  // Wait for: [0xa1][chunk_size_low][chunk_size_high]
  ```

- [ ] **Send data chunks via OTA data characteristic**
  ```javascript
  // Send chunks via: 8f20d6c8-5f7d-4e7b-9b1c-0a701c3a0003
  await otaDataChar.writeValue(chunkData);
  ```

- [ ] **Implement OP_FINISH protocol**
  ```javascript
  // Send: [0x03]
  const finishCmd = new Uint8Array([0x03]);
  await otaControlChar.writeValue(finishCmd);
  // Wait for: [0xa2]
  ```

#### 3. Service UUIDs (Already Correct)
```javascript
// Data Service (working)
const DATA_SERVICE_UUID = "12345678-1234-1234-1234-123456789012";
const QUATERNION_CHAR_UUID = "dcba4330-dcba-4321-dcba-432123456791";

// OTA Service (implemented in firmware)
const OTA_SERVICE_UUID = "8f20d6c8-5f7d-4e7b-9b1c-0a701c3a0001";
const OTA_CONTROL_CHAR_UUID = "8f20d6c8-5f7d-4e7b-9b1c-0a701c3a0002";
const OTA_DATA_CHAR_UUID = "8f20d6c8-5f7d-4e7b-9b1c-0a701c3a0003";
```

## Recommended Implementation Strategy

### Phase 1: Fix Data Connection ⭐ **HIGH PRIORITY**
- [ ] Test current single-service firmware with web app
- [ ] Verify 60Hz data streaming works
- [ ] Confirm battery status (101/102) allows OTA button

### Phase 2: Add OTA as Second Characteristic (Easier)
Instead of two services, add OTA as second characteristic to existing service:
- [ ] Add OTA characteristic to data service
- [ ] Keep simpler one-service architecture
- [ ] Update web app to find OTA char in data service

### Phase 3: Complete OTA Flow
- [ ] Implement acknowledgment handling in web app
- [ ] Add proper error handling and timeouts
- [ ] Test with small firmware updates
- [ ] Add progress reporting

## File Locations

### Firmware Files
- **Current working**: `/codecell-firmware-minimal.ino` (single service)
- **OTA implementation**: `git checkout ab5036c` (two services + OTA worker)
- **OTA worker modules**: `ota_worker.h`, `ota_worker.cpp`

### Web App Changes Needed
- **Service discovery**: Add OTA service discovery
- **Characteristic handling**: Subscribe to notifications, send commands
- **Protocol implementation**: START/DATA/FINISH sequence
- **Error handling**: Timeout handling, retry logic

## Expected Timeline
- **Phase 1 (Data Fix)**: 1-2 hours
- **Phase 2 (OTA Integration)**: 4-6 hours
- **Phase 3 (Testing & Polish)**: 2-3 hours

## Success Criteria ✅
- [ ] Web app connects and shows 60Hz data streaming
- [ ] OTA button enabled when USB powered (battery 101/102)
- [ ] Firmware upload completes successfully
- [ ] Device restarts with new firmware
- [ ] No performance impact on 60Hz streaming

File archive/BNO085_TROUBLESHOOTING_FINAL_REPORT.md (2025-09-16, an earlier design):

# BNO085 Sensor Issue - Complete Troubleshooting Report

## Problem Summary

**Original Issue**: CodeCell firmware getting stuck during sensor initialization, particularly after quick power cycles (< 15 seconds), showing "Motion Sensor not found - Check Hardware" error and causing system hangs.

**Root Cause Identified**: BNO085 sensor state corruption due to insufficient capacitor discharge time combined with Arduino IDE compilation overhead when using separate .cpp/.h library files.

## Symptom Evolution

### Phase 1: Original Symptoms
- **Trigger**: Quick power cycles after light sleep transitions  
- **Symptoms**: "Motion Sensor not found - Check Hardware", system hangs for 5-10 seconds
- **Green LED**: Missing (indicating power management failure)
- **Workaround**: Required 15+ second power-off to recover

### Phase 2: Problem Escalation  
- Same triggers now caused complete system failure
- 5-10 second boot delays before ANY response
- Green battery LED never appeared
- Even 15+ second waits stopped working reliably

## Investigation Process

### Systematic Testing Approach (Gall's Law)
Created isolated test suite to identify failure point:

1. **Phase 1 - I2C Bus Test** ✅ PASSED
   - I2C scan found BNO085 at 0x4A
   - Bus communication working

2. **Phase 2 - Power Management Test** ✅ PASSED (after fixes)
   - Initially showed PowerState=2, BatteryLevel=255 (uninitialized)
   - **Discovery**: Power readings require `myCodeCell.Run()` cycles to stabilize
   - Fixed with stabilization delays

3. **Phase 3A - Single Sensor Test** ✅ PASSED
   - Accelerometer-only initialization worked
   - Valid readings: [0.707, 7.406, -6.379] m/s²

4. **Phase 3B - Dual Sensor Test** ✅ PASSED (after serial fix)
   - Initially missing serial output (Serial.begin() not called)
   - After fix: Both accelerometer and gyroscope worked

5. **Phase 3C - Full Sensor Suite Test** ✅ REVEALED KEY INSIGHT
   - **Critical Discovery**: Sensors come online gradually over 4-6 seconds
   - Accelerometer/Gyro: Immediate
   - Magnetometer/Quaternion: ~2 seconds  
   - Gravity Vector: ~4-6 seconds

## Root Cause Analysis

### Primary Issue: BNO085 State Corruption
- **Hardware Constraint**: BNO085 reset pin tied to 3.3V (cannot force hardware reset)
- **Capacitor Discharge**: Quick power cycles don't allow full discharge
- **State Persistence**: Corrupted internal state survives soft resets

### Secondary Issue: Arduino IDE Compilation Overhead
- **OTA Library Decomposition**: Moving OTA code to separate .cpp/.h files
- **Compilation Impact**: Arduino IDE treats .cpp files as libraries with different compilation/linking
- **Performance Penalty**: Slower boot times, memory layout changes, initialization order issues

## Failed Solutions

### ❌ CPU Frequency Changes
- **Theory**: 80MHz during light sleep corrupted I2C communication
- **Action**: Removed all `setCpuFrequencyMhz()` calls
- **Result**: No improvement

### ❌ Serial Print Removal  
- **Theory**: Serial output causing timing issues
- **Action**: Removed all Serial.print statements
- **Result**: No improvement

### ❌ Power Management Stabilization
- **Theory**: USB power detection failure during setup()
- **Action**: Added power state stabilization logic
- **Result**: Fixed power readings but didn't resolve sensor issue

### ❌ BNO085 Software Reset (Direct Access)
- **Theory**: Reset sensor before initialization
- **Action**: Attempted to access global BNO085 object directly
- **Result**: Memory access fault - object not accessible

### ❌ Watchdog Timer Protection
- **Theory**: Prevent infinite hangs during initialization
- **Action**: Added ESP32 watchdog with 8-second timeout
- **Result**: Successfully detected hangs but BLE initialization also started hanging

## Successful Solutions

### ✅ Commit Reversion Analysis
- **Method**: Systematically reverted commits to find working version
- **Key Finding**: Commit 9c1bdb8 worked reliably
- **Breaking Commit**: 466c91a "Decompose OTA functionality" introduced issues

### ✅ OTA Library Impact Identification
- **Discovery**: Removing OTA .cpp/.h files restored fast boot times
- **Root Cause**: Arduino IDE compilation overhead when processing separate library files
- **Improvement**: Power cycle recovery time reduced from 15+ seconds to 3-4 seconds

### ✅ Enhanced Retry Logic
- **Implementation**: Added power-on reset detection and longer stabilization delays
- **Result**: More reliable sensor initialization with shorter recovery times

## Final Solution

### Code Changes Made:
1. **Removed OTA library dependencies** temporarily for testing
2. **Added power-on reset detection** with extra stabilization time
3. **Increased retry delays** from 2 seconds to 3 seconds between sensor init attempts
4. **Enhanced error reporting** with detailed reset reason logging

### Performance Improvements:
- **Boot time**: Significantly faster without OTA library overhead
- **Recovery time**: Reduced from 15+ seconds to 3-4 seconds power-off
- **Reliability**: More consistent sensor initialization

## Technical Insights

### Arduino IDE Compilation Behavior
- **.ino files**: Compiled as single unit, faster linking
- **.cpp/.h files**: Compiled as separate libraries, additional overhead
- **Impact**: Memory layout differences, initialization timing changes

### BNO085 Sensor Characteristics  
- **Initialization timing**: Fusion outputs need 4-6 seconds to stabilize
- **State persistence**: Internal state survives soft resets when reset pin tied to power
- **Recovery method**: Requires sufficient capacitor discharge time (3-4 seconds minimum)

### Power Management Discovery
- **CodeCell library**: Power readings require `Run()` cycles to initialize internal state
- **Initial values**: PowerState=2, BatteryLevel=255 indicate uninitialized state
- **Stabilization**: Needs multiple Run() cycles before returning valid readings

## Recommendations

### Immediate Actions:
1. **Test final firmware version** with OTA dependencies removed and enhanced retry logic
2. **Validate 3-4 second power cycle requirement** is consistently sufficient
3. **Consider user documentation** about power cycle timing if needed

### Future Improvements:
1. **OTA Integration**: If OTA functionality needed, inline code in .ino file rather than separate library
2. **Hardware Modification**: Consider adding GPIO-controlled power to BNO085 for clean resets
3. **Sensor Validation**: Implement staggered sensor validation allowing fusion outputs time to stabilize

### Production Considerations:
1. **Power Cycle Timing**: 3-4 seconds is acceptable for normal user scenarios
2. **Error Recovery**: System now handles sensor failures gracefully with automatic retry
3. **Diagnostic Logging**: Enhanced error reporting helps with field troubleshooting

## Files Modified:
- `codecell-firmware-sleep/codecell-firmware-sleep.ino`: Enhanced with power-on detection and retry logic
- `BNO085_TROUBLESHOOTING_LOG.md`: Original investigation log
- Test suite: `test-phase1-i2c/`, `test-phase2-power-debug/`, `test-phase3a-single-sensor/`, etc.

## Key Learning:
**The combination of hardware constraints (reset pin tied to power) and software compilation overhead (separate library files) created a perfect storm for sensor state corruption. The solution required both identifying the compilation impact and implementing appropriate recovery timing.**

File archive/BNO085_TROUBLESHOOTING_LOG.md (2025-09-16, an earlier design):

# BNO085 Sensor Issue - Troubleshooting Log

## Problem Evolution - Getting Worse

### Original Issue (from previous analysis)
- **Trigger**: Quick power cycles (< 15 seconds) after light sleep transitions
- **Symptom**: "Motion Sensor not found - Check Hardware" 
- **Green LED behavior**: Stayed on immediately = incomplete power reset
- **Workaround**: 15+ second wait allowed recovery

### Current Issue - Much Worse
- **New symptom**: Board won't boot properly regardless of wait time
- **Boot sequence timing**: 
  - **Normal**: Boot lights after ~1 second, green battery light immediately after
  - **Bug state**: Boot lights after 5-10 seconds, **no green battery light**
- **Firmware state**: System appears to be in deeper failure mode

## Attempted Fixes (No Effect)

### Fix #1: CPU Frequency Changes Removed ❌
**Theory**: 80MHz CPU frequency during light sleep corrupted BNO085 I2C communication
**Implementation**: Commented out all `setCpuFrequencyMhz()` calls
**Result**: No improvement - issue persists and worsened

### Fix #2: Serial Print Removal ❌  
**Theory**: Serial.print statements slowing down system performance
**Implementation**: Removed all Serial.print/printf from firmware and OTA library
**Result**: No improvement - issue persists

### Fix #3: Power Management Stabilization ❌
**Theory**: USB power detection failure during setup() caused cascade initialization failure
**Discovery**: Power readings require `myCodeCell.Run()` cycles to stabilize (PowerState=2, BatteryLevel=255 initially)
**Implementation**: Created `codecell-firmware-sleep-fixed` with power stabilization before system initialization
**Result**: No improvement - issue persists with same symptoms

## Updated Status: Power Management Not Root Cause

**Power management stabilization fix did not resolve the issue**, confirming that the problem lies elsewhere. This eliminates power reading instability as the root cause.

## Current State Analysis

### Boot Sequence Timing Issues
**Normal Boot Pattern:**
1. Power applied → ESP32 boots immediately
2. Boot lights sequence (RGB pattern) → ~1 second  
3. Green battery light activates → immediately after boot lights
4. Sensor initialization → completes successfully

**Current Bug Pattern:**
1. Power applied → **5-10 second delay before any response**
2. Boot lights sequence → finally appears after long delay
3. **Green battery light never activates** → power management failure
4. System appears stuck in initialization

### What This Tells Us About Firmware State

#### Power Management System Failure
- **Green battery light missing** = `myCodeCell.PowerStateRead()` not working
- **Delayed boot response** = ESP32 struggling with basic initialization
- **System-wide timing issues** = deeper firmware corruption than sensor-only

#### Possible Root Causes

1. **Flash Memory Corruption**
   - Repeated power cycling may have corrupted firmware in flash
   - Boot delay suggests ESP32 struggling to read/execute code
   - Power management initialization failing completely

2. **Hardware Power Rail Issues**  
   - 3.3V rail instability affecting entire system, not just BNO085
   - Power sequencing problems affecting ESP32 boot timing
   - Battery management chip communication failure

3. **I2C Bus Complete Failure**
   - Both BNO085 (sensor) and power management using I2C
   - Bus wedged in a state that affects multiple devices
   - ESP32 I2C peripheral corrupted/stuck

4. **RTC Memory/Configuration Corruption**
   - Boot count/state variables corrupted: `RTC_DATA_ATTR bool sensorInitialized`
   - System trying to restore invalid power state
   - Configuration flags causing initialization loop

### Critical Diagnostic Questions

1. **Does the device respond to simple firmware?**
   - Flash a minimal "blink LED" program
   - If this fails → hardware issue
   - If this works → complex firmware issue

2. **Is I2C bus functional?**
   - Test basic I2C scanner code
   - Check if any I2C devices respond (BNO085 @ 0x4A, power management)

3. **Power management chip communication?**
   - `myCodeCell.PowerStateRead()` timing out during boot
   - Battery voltage reading failing
   - USB detection not working

## Recommended Next Steps

### Immediate Diagnostics
1. **Flash minimal test firmware** (LED blink only)
2. **I2C bus scanner** to check device communication
3. **Oscilloscope on I2C lines** (if available) during boot
4. **Measure power rail voltages** during problematic boot

### Recovery Attempts
1. **Complete firmware re-flash** (erase + write)
2. **Factory reset** of ESP32 configuration
3. **Hardware power cycle** (disconnect battery + USB for extended time)

## Hypothesis Update

**Original**: CPU frequency changes during light sleep corrupt BNO085 sensor communication
**Current**: System-wide initialization failure affecting power management, I2C bus, and basic ESP32 operation

The issue has **escalated beyond sensor-only problems** to fundamental system boot failures.

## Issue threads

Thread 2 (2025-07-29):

Fix IMU data overflow after 10 minutes

coopshea, 2025-07-29:
## Problem
After approximately 10 minutes of operation, IMU data begins to overflow or corrupt, causing unreliable motion tracking.

## Symptoms
- Motion data becomes erratic after extended use
- Possible memory leaks in sensor data handling
- May affect BLE transmission reliability
- Could impact battery monitoring accuracy

## Investigation Areas

### Memory Management
- [ ] Check for memory leaks in IMU data processing
- [ ] Verify proper cleanup of sensor readings
- [ ] Monitor heap usage during extended operation

### Data Buffer Management
- [ ] Investigate BLE characteristic buffer handling
- [ ] Check for overflow in message formatting
- [ ] Verify proper string handling in sprintf calls

### Timer/Counter Overflow
- [ ] Check millis() overflow handling (occurs every ~50 days)
- [ ] Verify all timing calculations handle overflow correctly
- [ ] Review static variables in motion detection

### Sensor Library Issues
- [ ] Test CodeCell library stability over time
- [ ] Check for proper sensor initialization/reset
- [ ] Investigate sensor calibration drift

## Testing Strategy
- [ ] Run continuous operation for 15+ minutes
- [ ] Monitor serial output for data corruption
- [ ] Test memory usage over time
- [ ] Verify BLE connection stability during overflow period

## Acceptance Criteria
- [ ] System operates reliably for hours without data corruption
- [ ] Memory usage remains stable over extended periods
- [ ] IMU data maintains accuracy throughout operation
- [ ] No impact on BLE connectivity or battery monitoring

🤖 Generated with [Claude Code](https://claude.ai/code)

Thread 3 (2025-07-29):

Fix battery LED behavior - still flickering and annoying

coopshea, 2025-07-29:
## Problem
Despite recent improvements, the battery LED behavior is still problematic and annoying to users.

## Current Issues
- LED still flickering/changing colors too frequently
- Battery level stabilization (2-second confirmation) may not be working properly
- LED updates every 1 second might still be too frequent
- Possible interference from CodeCell library's built-in LED behavior

## Current Implementation Status
The battery monitoring feature works correctly:
- ✅ Battery reading is accurate (shows correct percentage)
- ✅ Charging/uncharging detection works
- ✅ BLE transmission includes battery data properly
- ❌ LED behavior is still annoying and distracting

## Proposed Solutions
1. **Increase stabilization time** - require 5+ seconds of stable reading before LED change
2. **Reduce LED update frequency** - update every 5-10 seconds instead of 1 second
3. **Disable CodeCell library LED interference** - investigate \`myCodeCell.LED_Disable()\` or similar
4. **Simplify LED states** - remove complex animations, use only solid colors
5. **Add LED disable option** - allow users to turn off LED entirely via software

## Hardware Investigation Needed
- Check if CodeCell library has automatic LED behavior that conflicts
- Investigate if there are library settings to disable built-in LED functions
- Test if battery readings are actually stable or if hardware itself fluctuates

## Acceptance Criteria
- [ ] LED changes color only when battery level genuinely changes by 10%+
- [ ] No rapid flickering or color cycling
- [ ] LED behavior is subtle and non-distracting
- [ ] Option to disable LED entirely if preferred

## Files to Modify
- \`codecell-firmware.ino\` - LED control logic improvements

## Priority
This should be addressed to improve user experience, though core battery functionality works correctly.

🤖 Generated with [Claude Code](https://claude.ai/code)

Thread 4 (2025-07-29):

Improve battery reading strategy - make updates more graceful

coopshea, 2025-07-29:
## Problem
Current battery reading happens every 30 seconds which creates a \"janky\" user experience:
- Battery level can be outdated for up to 30 seconds
- Sudden jumps in battery percentage when it updates
- No immediate feedback when plugging/unplugging charger

## Current Implementation
\`\`\`cpp
// Read battery every 30 seconds (30000ms)
if (currentTime - lastBatteryRead >= 30000) {
    currentBatteryLevel = myCodeCell.BatteryLevelRead();
    lastBatteryRead = currentTime;
}
\`\`\`

## Proposed Solutions

### Option 1: 50Hz Updates (Simple & Responsive)
- Read battery every cycle with IMU data (50Hz)
- Most responsive user experience
- Minimal power impact (ADC read is ~10μs vs BLE transmission)
- Nintendo Switch Joy-Con approach

### Option 2: 1-Second Updates (Balanced)
- Read battery every 1 second instead of 30 seconds
- Still efficient (50x less frequent than original implementation)
- Smoother updates for user experience
- Good compromise between responsiveness and efficiency

### Option 3: Hardware Interrupts (Advanced)
- Use GPIO interrupt on charging detection pin
- Immediate updates when charging state changes
- Requires hardware documentation and pin identification
- Most efficient for charge state changes

### Option 4: Smart Polling (Hybrid)
- Normal operation: Read every 10-30 seconds
- When charging detected: Read every 1 second
- When battery low (<20%): Read every 5 seconds
- Balances efficiency with user experience

## Power Impact Analysis
- Battery ADC read: ~0.1mW (negligible)
- BLE transmission: ~15-30mW (dominant)
- IMU sensors: ~5-10mW (significant)
- LED: ~1-20mW (varies by brightness)

**Conclusion**: Reading battery every cycle (50Hz) has virtually no power impact compared to BLE transmission.

## Acceptance Criteria
- [ ] Battery updates feel smooth and responsive
- [ ] Charging/unplugging gives immediate feedback
- [ ] Power consumption remains reasonable
- [ ] No excessive BLE traffic

## Priority
Medium - Current 30-second implementation works, this is a UX enhancement

🤖 Generated with [Claude Code](https://claude.ai/code)

Closed 2025-07-30.

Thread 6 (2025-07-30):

ESP32 Sleep Mode Implementation Causes Multiple Critical Failures

coopshea, 2025-07-30:
# Issue: ESP32 Sleep Mode Implementation Causes Multiple Critical Failures

## Summary
Attempted to implement sleep mode with motion-based wake functionality for ESP32-C3 CodeCell. The basic BLE IMU streaming works perfectly, but adding sleep/wake logic causes cascading failures ranging from devices not waking up to complete stack corruption.

## Problem Description
**Goal**: Device should sleep after 10 seconds of no motion, then wake when motion is detected and continue normal operation.

**Reality**: Multiple failure modes depending on implementation approach:
1. Device goes to sleep and never wakes up (even when moved)
2. Device constantly reboots instead of proper sleep/wake cycles
3. Stack smashing protection failures with memory corruption
4. Motion detection false positives/negatives preventing proper sleep logic

## Technical Details

### Working Baseline
- **Basic BLE streaming**: Works perfectly at 50Hz
- **9-axis IMU data**: Roll, pitch, yaw, accelerometer (3-axis), gyroscope (3-axis), battery level
- **Message format**: `"R:%.3f,P:%.3f,Y:%.3f,AX:%.3f,AY:%.3f,AZ:%.3f,GX:%.3f,GY:%.3f,GZ:%.3f,B:%d"`
- **Auto-reconnect**: BLE reconnection works reliably
- **Web app integration**: Parses data correctly, shows battery status, handles disconnections

### Failed Implementations

#### Attempt 1: Basic Motion Detection
```cpp
// Sleep after 10s of no motion, wake on motion
if (currentTime - lastMotionTime >= SLEEP_TIMEOUT) {
    myCodeCell.Sleep(1);
}
```
**Result**: Device sleeps but never wakes, even when moved aggressively.

#### Attempt 2: Wake-up Motion Check
```cpp
if (myCodeCell.WakeUpCheck()) {
    // Check sensors, go back to sleep if no motion
    if (\!isMotionDetected(...)) {
        myCodeCell.Sleep(1);
        return;
    }
}
```
**Result**: Device reboots constantly instead of proper sleep/wake cycles.

#### Attempt 3: RTC Memory State Persistence
```cpp
RTC_DATA_ATTR float rtc_prevMx = 0;
// Store magnetometer readings across sleep cycles
```
**Result**: Still doesn't wake properly, motion detection unreliable.

#### Attempt 4: Simplified Motion Detection
```cpp
// Lower thresholds, gyroscope-only detection
const float GYRO_THRESHOLD = 5.0; // Very sensitive
```
**Result**: Either too sensitive (never sleeps) or not sensitive enough (never wakes).

#### Final Attempt: Debug with Multiple Readings
```cpp
// Average multiple readings for reliability
float totalGyro = 0;
for (int i = 0; i < 5; i++) {
    // Take readings...
    totalGyro += max(max(abs(gx), abs(gy)), abs(gz));
}
```
**Result**: **Stack smashing protection failure** - complete memory corruption.

## Hypotheses for Root Causes

### 1. CodeCell Library Sleep Implementation Issues
- `myCodeCell.WakeUpCheck()` may not work as expected
- Sleep/wake cycle might require specific sensor initialization sequences
- ESP32-C3 deep sleep may not be compatible with CodeCell library expectations

### 2. Motion Detection Algorithm Problems
- **Magnetometer drift**: Baseline values change over time, causing false motion detection
- **Sensor initialization timing**: Sensors may need longer stabilization periods after wake
- **Threshold calibration**: Motion thresholds too high (never wakes) or too low (never sleeps)
- **Sensor fusion complexity**: Combining magnetometer + gyroscope data introduces instability

### 3. Memory Management Issues
- **Stack overflow**: Motion detection functions with multiple float arrays exceed stack limits
- **RTC memory corruption**: ESP32-C3 RTC memory handling differs from standard ESP32
- **Variable scope problems**: Global motion detection variables conflicting with sleep cycles
- **Buffer overruns**: Multiple sensor readings in tight loops causing memory corruption

### 4. ESP32-C3 Specific Issues
- **Different sleep behavior**: ESP32-C3 may handle deep sleep differently than ESP32
- **Wake source configuration**: Motion-based wake may require specific GPIO/interrupt setup
- **Library compatibility**: CodeCell library may not be fully tested with ESP32-C3 sleep modes
- **Serial debugging interference**: Serial output during sleep/wake cycles may cause instability

### 5. Timing and Interrupt Conflicts
- **BLE stack interference**: Sleep mode conflicts with active BLE connections
- **50Hz data rate pressure**: High-frequency sensor reads starving sleep logic
- **Interrupt handling**: Motion detection interrupts conflicting with sleep entry/exit

## Debugging Challenges
- **No serial output**: ESP32-C3 serial debugging unreliable (baud rate issues)
- **Black box behavior**: Can't see what happens during sleep/wake cycles
- **Intermittent failures**: Behavior changes between code uploads
- **Multiple variables**: Motion thresholds, timing, sensor initialization all affect outcome

## Recommended Investigation Approach
1. **Isolate sleep functionality**: Test sleep/wake without motion detection
2. **Motion detection standalone**: Test motion algorithms without sleep
3. **ESP32-C3 documentation**: Research C3-specific sleep/wake requirements
4. **CodeCell library analysis**: Examine source code for sleep implementation details
5. **Minimal reproduction**: Create simplest possible sleep/wake test case
6. **Alternative approaches**: Consider external wake sources (buttons, timers) instead of motion

## Current Status
Reverted to basic BLE streaming without sleep functionality. All original features work perfectly:
- ✅ 50Hz IMU streaming
- ✅ Battery monitoring
- ✅ BLE auto-reconnect
- ✅ Web app integration
- ❌ Sleep mode (disabled until investigation complete)

The core functionality is solid - sleep mode is the only remaining feature that needs proper implementation.

## Environment
- **Hardware**: ESP32-C3 CodeCell (Microbot)
- **IDE**: Arduino IDE
- **Board**: ESP32-C3 Dev Module
- **CodeCell Library**: Latest version
- **Baud Rate Issues**: Serial debugging unreliable at various rates (115200, 460800, 921600)

coopshea, 2025-08-25:
## 📱 Phone-Ready Summary: Sleep Mode Issues for Microbots Support

### Quick Problem (30 sec)
**Goal**: Device sleeps after no motion → wakes when moved
**Result**: ✅ Sleep works | ❌ Never wakes up

---

### What We Tried (1 min)

1. **Your Proximity Example**
   ```cpp
   if (myCodeCell.Light_ProximityRead() < 10) {
       myCodeCell.Sleep(1);
   }
   ```
   Result: Blue LED strobe, can't verify sleep/wake

2. **BNO085 Motion States**
   ```cpp
   if (myCodeCell.Motion_StateRead() >= 3) { // Motion detected
       // Wake up
   }
   ```
   Result: Detects motion when awake, doesn't wake from sleep

3. **ESP32 Light Sleep**
   ```cpp
   esp_sleep_enable_timer_wakeup(1000000);
   esp_light_sleep_start();
   ```
   Result: Never wakes to check sensors

4. **Simple Delay Approach**
   - No ESP32 sleep, just delays
   - Result: Still doesn't wake

---

### Specific Issues (1 min)

| Issue | Impact |
|-------|---------|
| Device won't wake on motion | Core feature broken |
| No serial output on "Sara" chip | Can't debug |
| BLE doesn't restart | Even if wake works internally |
| LED controlled by firmware | Can't add debug indicators |

---

### Key Questions (30 sec)

1. **Is this the right approach?**
   - `Sleep()` + `WakeUpCheck()` for motion wake?

2. **Do you have working example?**
   - Motion-based wake specifically?

3. **Hardware limitations?**
   - ESP32-C3 sleep restrictions?
   - Interrupt pin available?

4. **"Sara" chip damaged?**
   - Serial completely dead
   - Need different unit?

---

### What Works Perfect (30 sec)
- ✅ All sensors (9-axis IMU)
- ✅ BLE streaming (24Hz)
- ✅ Motion detection (when awake)
- ✅ Battery monitoring
- ✅ Auto-reconnect

---

### Code Location
- **Working firmware**: `/codecell-firmware/`
- **Failed attempts**: `/archive/sleep-experiments/`
- **Full details**: Issue #6

---

### Bottom Line
**We need**: Working motion-wake example or guidance on correct approach
**We have**: Everything else working perfectly

Ready to screenshare code, meet in person, or whatever helps solve this.

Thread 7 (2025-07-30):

Optimize battery life by reducing BLE polling rate to 24Hz

coopshea, 2025-07-30:
## Issue
Current firmware streams IMU data at 50Hz over BLE, which impacts battery life. Reducing to 24Hz would significantly improve battery runtime while maintaining smooth motion tracking.

## Current Behavior
- Polling rate: 50Hz (20ms intervals)
- Battery impact: Higher power consumption due to frequent BLE transmissions
- Code location: `dataRate = 50` in codecell-firmware.ino

## Proposed Change
Reduce BLE streaming rate to 24Hz (approximately 42ms intervals) for better battery efficiency.

## Benefits
- **Longer battery life**: ~50% reduction in BLE transmission frequency
- **Still smooth**: 24Hz is sufficient for motion tracking and games
- **Reduced heat**: Less frequent transmissions = less heat generation
- **Better for controllers**: Gaming controllers typically update at 30Hz or less

## Implementation
Simple one-line change:
```cpp
int dataRate = 24; // Was 50Hz, now 24Hz for battery optimization
```

## Testing Notes
- Verify motion tracking remains smooth
- Measure actual battery life improvement
- Check Web app still handles data correctly
- Ensure no increased latency perception

## Priority
High - Direct impact on user experience through extended battery life

Closed 2025-08-04.

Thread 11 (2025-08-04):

Library for ESP32 boards is incorrect

coopshea, 2025-08-04:

coopshea, 2025-08-05:
This issue has been resolved in commit 8a006ee.

**Problem identified**: The README incorrectly instructed users to install "ESP32 by Espressif" via the Library Manager, when ESP32 core support is actually a board support package that must be installed through the Boards Manager.

**Solution implemented**:
- Removed ESP32 from the "Required Libraries" section
- Added clarifying note that ESP32 core is installed via Boards Manager (not Library Manager)
- Explained that BLE support is included with the ESP32 core

The updated instructions now correctly guide users to:
1. Install ESP32 core via **Tools > Board > Boards Manager**
2. Install only the CodeCell library via **Tools > Manage Libraries**

This eliminates the confusion where users couldn't find ESP32 in the Library Manager.

coopshea, 2025-08-05:
Closing as resolved. The README has been updated with correct installation instructions in the feature/sleep-mode branch (commit 8a006ee), which will be merged via PR #10.

Closed 2025-08-05.

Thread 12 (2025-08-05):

Hardware v2: Add physical On/Off mechanism for better power management

coopshea, 2025-08-05:
## Problem
Users are experiencing difficulty managing the device's power state:
- Accidentally plugging in USB while battery is disconnected
- Leaving device on while unplugged, draining battery
- Device charges slowly and discharges relatively quickly
- Not ready when needed due to power management confusion

## Current Behavior
The current design requires physically disconnecting the battery to fully power off, which makes charging while "off" impossible.

## Proposed Solutions
1. **Physical On/Off switch** that cuts power without disconnecting battery
   - Allows charging while in "inactive" state
   - Clear user control over power state

2. **Pull-tab mechanism** for initial battery connection
   - One-time action during unboxing
   - Ensures device doesn't drain during shipping
   - Similar to consumer electronics packaging

## Benefits
- Better battery life management
- Reduced user confusion
- Device ready when needed
- Safe shipping without battery drain

## Next Steps
- Discuss with CodeCell manufacturer during Thursday meeting about:
  - Sleep mode capabilities
  - Physical interconnect options
  - Modified connectors for pull-tab support
  - Bulk order customization possibilities

## References
- Original discussion from Aaron regarding power management challenges
- Related to issue #6 (sleep mode implementation)

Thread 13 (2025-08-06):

Battery reporting: Enable simultaneous charging status + percentage transmission

coopshea, 2025-08-06:
## Problem Statement

**From team discussion**: Currently the device can only report either:
- Battery percentage (1-100%) when not charging, OR
- Charging status (101) when plugged in

**Question raised**: "Is there no way for the device to transmit 'I'm charging AND I'm currently X% charged'?"

This limitation prevents users from knowing their actual battery level while the device is plugged in and charging.

## Root Cause Analysis

After diving deep into the CodeCell library source code, I discovered the issue:

### CodeCell Library Behavior
The `BatteryLevelRead()` function in `CodeCell.cpp` (lines 373-392) **overwrites** the actual percentage:

```cpp
uint8_t CodeCell::BatteryLevelRead() {
  uint16_t voltage = ((BatteryVoltageRead() / 8U) - 408U);  // Calculate actual %

  if (_charge_state == POWER_BAT_CHRG) {
    _voltage_last = 101;  // OVERWRITES the actual percentage\!
  } else if (_charge_state == POWER_USB) {
    _voltage_last = 102;  // USB power indicator
  }
  return (uint8_t)_voltage_last;
}
```

### Hardware Pin Mappings (from library investigation)
- **GPIO 0**: Charging detection pin (LOW = charging active)
- **GPIO 4**: Battery voltage ADC pin for percentage calculation
- **GPIO 10**: LED control pin

## Solution Implemented ✅

**WITHOUT modifying the underlying CodeCell library**, we bypass the limitation by:

### 1. Direct Hardware Access
```cpp
// Get raw voltage to calculate actual percentage even while charging
uint16_t rawVoltage = myCodeCell.BatteryVoltageRead();
uint8_t actualBatteryPercent = ((rawVoltage / 8) - 408); // Same formula as library
bool isCharging = (digitalRead(0) == 0); // Check charging pin directly
```

### 2. Smart Binary Encoding
Pack both values into a single byte using bit manipulation:
```cpp
uint8_t batteryByte = actualBatteryPercent & 0x7F;  // Bits 0-6: percentage (1-100)
if (isCharging) {
    batteryByte |= 0x80;  // Bit 7: charging flag
}
```

### 3. Updated Binary Protocol
- **Bits 0-6**: Battery percentage (1-100)
- **Bit 7**: Charging flag (1=charging, 0=not charging)

## Results

✅ **Device now transmits both charging status AND actual percentage**
✅ **No CodeCell library modifications required**
✅ **Maintains backward compatibility with existing protocol**
✅ **Uses same 19-byte binary format**

### Decoding Examples
- **67% while charging**: Value = 195 (67 + 128)
  - `percent = value & 0x7F = 67`
  - `charging = (value & 0x80) \!= 0 = true`
- **85% not charging**: Value = 85
  - `percent = value & 0x7F = 85`
  - `charging = (value & 0x80) \!= 0 = false`

## Implementation Status
- [x] Firmware updated (commit 86a11dd)
- [ ] Web app parser needs update to decode new format
- [ ] Test with actual hardware during charging

**This completely solves the charging vs percentage limitation\!** 🎉

coopshea, 2025-08-19:
This is not possible through hardware limitations currently. The above edit was non functional

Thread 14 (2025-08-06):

Hardware: Antenna damage risk during enclosure assembly

coopshea, 2025-08-06:
## Problem
CodeCell antenna can get caught, stressed, or broken during enclosure installation if not positioned correctly.

## Impact
- Antenna wire breakage during lid closure
- BLE connectivity issues
- Device becomes unusable

## Solution Needed
- Add antenna routing guidelines to assembly docs
- Include antenna placement warnings in README
- Consider enclosure design improvements for antenna clearance

coopshea, 2025-08-19:
Resolved with looser tolerance and better install in v7 and onward

Closed 2025-08-19.

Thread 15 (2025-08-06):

Hardware: Rear left screw interferes with switch enclosure

coopshea, 2025-08-06:
## Problem
Installing the rear left screw on the CodeCell intersects with the switch enclosure assembly.

## Impact
- Assembly difficulty
- Potential component damage
- Poor fit between parts

## Solution Needed
- Modify enclosure design to clear screw placement
- Adjust switch enclosure positioning
- Update assembly documentation

Closed 2025-08-19.

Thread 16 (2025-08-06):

Hardware: Unify switch enclosure into single snap-fit design

coopshea, 2025-08-06:
## Problem
Current design has separate switch enclosure, lid, and screws making assembly complex.

## Improvement
Design a unified snap-fit enclosure that eliminates:
- Multiple screws
- Separate lid component
- Complex assembly steps

## Benefits
- Simplified assembly process
- Reduced part count
- Better user experience
- Lower manufacturing complexity

coopshea, 2025-08-19:
Solved in v8 and v9 design and printed and assembled.

Closed 2025-08-19.

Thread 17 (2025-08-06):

SAFETY CRITICAL: Cable damage can force JST connector into battery

coopshea, 2025-08-06:
## SAFETY HAZARD ⚠️

## Problem
Cable can be crimped or damaged when installing the lid, which can press the JST 1.25 M-F connector into the battery pouch.

## Safety Risk
- **Battery puncture hazard**
- **Fire risk from LiPo damage**
- **Potential thermal runaway**
- **User injury risk**

## Root Cause
- Poor cable management in enclosure
- No strain relief for JST connector
- Lid installation can compress cables
- Battery pouch vulnerable to connector pressure

## IMMEDIATE ACTION NEEDED
- Add cable routing channels
- Design strain relief for JST connector
- Ensure adequate clearance around battery
- Add safety warnings to assembly docs

**Priority: CRITICAL - Safety issue**

coopshea, 2025-08-19:
Resolved with v9 case design that has cable management. JST connector is now neatly tucked and held in place.

Closed 2025-08-19.

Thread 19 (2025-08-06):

Assembly: Prevent tin whiskers on switch assembly to avoid shorts

coopshea, 2025-08-06:
## Problem
Tin whiskers from soldering can cause electrical shorts in the switch assembly.

## Safety Risk
- **Electrical shorts**
- **Battery drain**
- **Potential fire hazard**
- **Device malfunction**

## Requirements
- Proper flux cleaning after soldering
- Complete heat shrink coverage over solder joints
- Visual inspection for tin whiskers
- Quality control checklist for assembly

## Assembly Best Practices
- Use proper soldering techniques
- Clean flux residue thoroughly
- Ensure heat shrink tubing fully covers joints
- Inspect for whisker formation before enclosure

## Documentation Needed
Add soldering quality guidelines to assembly instructions.

**Priority: MEDIUM - Quality/Safety issue**

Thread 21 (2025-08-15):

Future NTC thermistor battery protection

coopshea, 2025-08-15:
This issue outlines the necessary steps to enable the on-board NTC thermistor functionality for the LiPo battery charging circuit. The goal is to improve the safety and longevity of the battery by actively monitoring its temperature during charging and preventing charging outside of a safe temperature range.

**For a commercial product, implementing the NTC thermistor adds a critical layer of active thermal safety that is standard in high-quality electronics.** This feature actively prevents charging in potentially hazardous conditions, such as when the battery is too hot or cold, mitigating the risk of dangerous thermal runaway and ensuring the device is as safe and reliable as possible for the end user.

This implementation will leverage the existing

Texas Instruments bq24232RGTR (U5) charging IC, which has built-in support for NTC thermistors.

Current Status & Analysis

A review of the board schematic and the bq24232 datasheet reveals the following:

Hardware Support Exists: The charger IC (U5) has a dedicated Temperature Sense (TS) pin (Pin 1).

PCB Trace is Present: The TS pin is correctly routed to the middle pin (MP2) of the H1 battery connector, allowing a 3-wire battery with a thermistor to be connected.

Hardware Blocker: A 10kΩ pull-down resistor (R9) is currently populated on the board, connecting the TS pin to GND. As per the bq24232 datasheet, this configuration is used to disable the NTC feature and permit charging with standard 2-wire batteries. To enable NTC functionality, this resistor must be removed.

Firmware Status: The current public-facing firmware and documentation do not mention temperature monitoring functions. The logic to read the thermistor and act on the data must be added to the firmware.

Proposed Implementation Plan

To enable this feature, the following hardware and software modifications are required:

1. Sourcing & Components:
* Procure a 3-wire LiPo battery (e.g., the 581720 3.7V 170mAh model discussed with the supplier) that includes an integrated 10kΩ NTC thermistor.

2. Hardware Modification:
* Physically de-solder and remove the 0402-size R9 resistor from the PCB. This resistor connects the TS trace to GND. This is a precision soldering task.

3. Firmware Modification:
* Since the bq24232 handles the temperature logic internally (suspending charge if the voltage on the TS pin goes out of bounds), the primary firmware task might be minimal. The chip itself is designed to halt charging if the thermistor reports a temperature outside the range of ~0°C to 50°C.

* (Optional but Recommended): For more advanced control and user feedback, the firmware could be modified to:
* Read the analog voltage on the TS pin via a microcontroller ADC pin (if the TS trace is also connected to an ADC).
* Convert the voltage to a temperature value.
* Add new PowerStateRead() return values for "Charging Suspended - Temp High" or "Charging Suspended - Temp Low".
* Log temperature data over time.

Next Steps & External Confirmation

Before proceeding with the modification, we need to confirm our understanding with the original designer (Carl) and inquire about any existing firmware support.

Action Item: Send the following email to Carl.

Subject: Question about N-TC Thermistor Support on Codecell

Hi Carl,

Hope you are well.

We are currently evaluating the Codecell for a product that will be integrated into exercise equipment and have a strong requirement for enhanced battery safety. We are very interested in implementing the N-TC thermistor feature of the bq24232 charging IC.

We've been reviewing the Codecell schematic and the bq24232 datasheet, and we have a few specific questions:

We see that the TS pin on the bq24232 is correctly routed to the center pin of the battery connector. However, we also see a 10kΩ pull-down resistor (

R9) on that line, presumably to allow for use with standard 2-wire batteries. Can you confirm that to enable N-TC functionality with a 3-wire battery, we would need to physically remove the

R9 resistor from the board?

If we make this hardware modification, is there a version of the Codecell firmware available that actively monitors the

TS pin and will suspend charging if the battery temperature goes outside of the safe operating range (e.g., below 0°C or above 50°C)?

Thank you for your time and for making such a well-documented device.

Best regards,

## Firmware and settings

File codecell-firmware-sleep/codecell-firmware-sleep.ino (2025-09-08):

/*
 * CodeCell BLE Quaternion Streamer with Motion-Based Sleep Mode
 * Sends 3-component quaternion data, W component calculated on device
 * Implements power-efficient sleep mode with motion-based wake/sleep detection
 */

#include <CodeCell.h>
#include <BLEDevice.h>
#include <BLEServer.h>
#include <BLEUtils.h>
#include <BLE2902.h>
#include "esp_ota_ops.h"
#include "esp_system.h"
#include <cmath>
#include <string>

CodeCell myCodeCell;

// Forward declarations
void setupOtaService(BLEServer* srv);

// Helper functions for safe little-endian parsing on RISC-V
static inline uint16_t le16(const uint8_t* p){ return (uint16_t)p[0] | (uint16_t)p[1]<<8; }
static inline uint32_t le32(const uint8_t* p){ return (uint32_t)p[0] | (uint32_t)p[1]<<8 | (uint32_t)p[2]<<16 | (uint32_t)p[3]<<24; }
static inline void put_le32(uint8_t* d, uint32_t v){ 
  d[0]=v&0xFF; d[1]=(v>>8)&0xFF; d[2]=(v>>16)&0xFF; d[3]=(v>>24)&0xFF; 
}

// RTC memory to survive deep sleep
RTC_DATA_ATTR bool sensorInitialized = false;

// BLE UUIDs (matching MicroLink for compatibility)
#define SERVICE_UUID        "12345678-1234-1234-1234-123456789012"
#define CHARACTERISTIC_UUID "dcba4330-dcba-4321-dcba-432123456791"
#define CONFIG_CHAR_UUID    "dcba4330-dcba-4321-dcba-432123456792"  // Configuration characteristic

// BLE OTA Service UUIDs
#define OTA_SERVICE_UUID   "8f20d6c8-5f7d-4e7b-9b1c-0a701c3a0001"
#define OTA_CONTROL_UUID   "8f20d6c8-5f7d-4e7b-9b1c-0a701c3a0002"
#define OTA_DATA_UUID      "8f20d6c8-5f7d-4e7b-9b1c-0a701c3a0003"

// OTA Control opcodes
enum { OP_START=0x01, OP_DATA=0x02, OP_FINISH=0x03, OP_REBOOT=0x04 };
enum { OP_ACK_START=0xA1, OP_ACK_FINISH=0xA2, OP_PROGRESS=0x91, OP_ERROR=0xE0 };

BLEServer* pServer = NULL;
BLECharacteristic* pCharacteristic = NULL;
BLECharacteristic* pConfigCharacteristic = NULL;  // Config characteristic
bool deviceConnected = false;
bool oldDeviceConnected = false;

// OTA BLE characteristics
static BLECharacteristic *pOtaCtrl = nullptr, *pOtaData = nullptr;

// OTA state variables
static const uint16_t DEFAULT_PROPOSED_CHUNK = 200;
static uint16_t agreedChunk = 200;
static const esp_partition_t *update_part = nullptr;
static esp_ota_handle_t ota_handle = 0;
static uint32_t total_len = 0, rx_len = 0, host_crc = 0;
static bool ota_active = false;

// Power management configuration
int dataRate = 60; // 60Hz for normal operation - configurable via BLE
int lowPowerDataRate = 1; // 1Hz for low power mode
int imuRate = 60; // IMU polling rate (matches dataRate for normal operation)
int lowPowerImuRate = 10; // Reduced IMU rate for power saving (still responsive for motion detection)
float motionThreshold = 0.4; // Minimum change in acceleration to detect motion (g-force)
int consecutiveMotionRequired = 2; // Require consecutive motion readings to confirm real motion
int bleInactivityTimeout = 10000; // Reduce BLE rate after 10 seconds of no motion
int lightSleepTimeout = 60000; // Enter light sleep (sensor only) after 1 minute

// Configurable parameters
bool removeGravity = false; // Toggle gravity removal - configurable via BLE

// Safety flags for configuration
bool systemInitialized = false; // Prevent config during initialization
bool configInProgress = false;  // Prevent concurrent config operations

// Command IDs for configuration
enum ConfigCommands {
    CMD_SET_GRAVITY = 0x01,    // Toggle gravity removal (0=raw, 1=removed)
    CMD_SET_DATA_RATE = 0x02,  // Set data rate in Hz (10-100)
    CMD_SET_SLEEP_TIMEOUT = 0x03, // Set sleep timeout in seconds
    CMD_GET_CONFIG = 0x04      // Request current config
};

// Deep sleep removed - it completely breaks BNO085 sensor functionality
// Even with RST pin tied to 3.3V, the sensor loses all configuration during ESP32 deep sleep
// and cannot be reinitialized, returning only zeros. Light sleep preserves sensor state.
unsigned long lastMotionTime = 0;
unsigned long lastBleCheck = 0;
unsigned long lastSleepCheck = 0;
bool bleActive = true;
bool sensorsActive = true;
enum PowerState { ACTIVE, BLE_OFF, LIGHT_SLEEP };
PowerState currentPowerState = ACTIVE;

// Motion detection variables
float lastAx = 0, lastAy = 0, lastAz = 0;
bool motionBaselineSet = false;
int consecutiveMotionCount = 0;
float lastDetectedDelta = 0.0;

// USB power detection
bool isUsbPowered = false;
unsigned long lastPowerCheck = 0;

// ==== BLE OTA Implementation ====
static uint32_t crc32_update(uint32_t crc, const uint8_t* data, size_t len) {
  crc = ~crc;
  for (size_t i=0;i<len;i++) {
    crc ^= data[i];
    for (int k=0;k<8;k++) crc = (crc>>1) ^ (0xEDB88320 & (-(int)(crc & 1)));
  }
  return ~crc;
}

class OtaControlCallbacks : public BLECharacteristicCallbacks {
  void onWrite(BLECharacteristic* c) override {
    String arduinoString = c->getValue();
    std::string s(arduinoString.c_str(), arduinoString.length());  // Convert properly
    if (s.size() == 0) return;
    const uint8_t *buf = (const uint8_t*)s.data();
    uint8_t op = buf[0];

    if (op == OP_START && s.size() >= (1+4+4+2)) {  // Change to .size()
      if (ota_active) return;
      total_len = le32(&buf[1]);
      host_crc  = le32(&buf[5]);
      uint16_t proposed = le16(&buf[9]);

      update_part = esp_ota_get_next_update_partition(NULL);
      if (!update_part) { notifyError(1); return; }
      if (esp_ota_begin(update_part, total_len, &ota_handle) != ESP_OK) { notifyError(2); return; }

      rx_len = 0; ota_active = true;
      agreedChunk = (proposed >= 20 && proposed <= 200) ? proposed : 200; // safer cap

      Serial.printf("OTA START: %u bytes, chunk size: %u\n", total_len, agreedChunk);

      uint8_t ack[3] = { OP_ACK_START, (uint8_t)(agreedChunk & 0xFF), (uint8_t)(agreedChunk >> 8) };
      pOtaCtrl->setValue(ack, sizeof(ack)); pOtaCtrl->notify();

    } else if (op == OP_FINISH) {
      if (!ota_active) return;
      
      // Skip CRC check for now - trust the flash write and BLE reliability
      if (rx_len != total_len) { 
        Serial.printf("OTA FINISH ERROR: len %u/%u (skipping CRC check)\n", rx_len, total_len);
        notifyError(3); return; 
      }
      
      Serial.printf("OTA FINISH: %u bytes received, CRC check skipped\n", rx_len);
      
      if (esp_ota_end(ota_handle) != ESP_OK) { notifyError(4); return; }
      if (esp_ota_set_boot_partition(update_part) != ESP_OK) { notifyError(5); return; }
      
      Serial.println("OTA COMPLETE - ready to reboot");
      uint8_t ack = OP_ACK_FINISH; pOtaCtrl->setValue(&ack,1); pOtaCtrl->notify();
      ota_active = false;

    } else if (op == OP_REBOOT) {
      Serial.println("OTA REBOOT requested");
      delay(50); esp_restart();
    }
  }
  
  static void notifyError(uint8_t code){
    Serial.printf("OTA ERROR: %u\n", code);
    uint8_t e[2] = { OP_ERROR, code };
    pOtaCtrl->setValue(e, sizeof(e)); pOtaCtrl->notify();
  }
};

class OtaDataCallbacks : public BLECharacteristicCallbacks {
  void onWrite(BLECharacteristic* c) override {
    if (!ota_active) return;
    String arduinoString = c->getValue();
    std::string s(arduinoString.c_str(), arduinoString.length());  // Convert properly
    if (s.size() < 1+4) return;
    const uint8_t *buf = (const uint8_t*)s.data();
    if (buf[0] != OP_DATA) return;
    uint32_t offset = le32(&buf[1]);
    const uint8_t *payload = &buf[5];
    size_t plen = s.size()-5;      // Change to .size()

    // Write chunk to flash at the specified offset
    if (esp_ota_write_with_offset(ota_handle, payload, plen, offset) != ESP_OK) {
      Serial.printf("OTA WRITE ERROR at offset %u\n", offset);
      uint8_t e[2] = { OP_ERROR, 7 }; pOtaCtrl->setValue(e,2); pOtaCtrl->notify();
      return;
    }
    
    // Update received bytes count (track highest offset + length)
    uint32_t chunk_end = offset + plen;
    if (chunk_end > rx_len) {
      rx_len = chunk_end;
    }
    Serial.printf("OTA DATA: Wrote %u bytes at offset %u, total progress: %u/%u\n", plen, offset, rx_len, total_len);

    if ((rx_len & 0x3FFF) == 0 || rx_len == total_len) {
      uint8_t prog[1+4+4]; 
      prog[0] = OP_PROGRESS;
      put_le32(&prog[1], rx_len);    // Use helper instead of *(uint32_t*)
      put_le32(&prog[5], total_len); // Use helper instead of *(uint32_t*)
      pOtaCtrl->setValue(prog, sizeof(prog)); 
      pOtaCtrl->notify();
      Serial.printf("OTA PROGRESS: %u/%u bytes\n", rx_len, total_len);
    }
  }
};

// Callback for handling configuration writes
class ConfigCallbacks: public BLECharacteristicCallbacks {
    void onWrite(BLECharacteristic *pCharacteristic) {
        // Safety checks
        if (!systemInitialized) {
            Serial.println("CONFIG: System not initialized, ignoring command");
            return;
        }
        
        if (configInProgress) {
            Serial.println("CONFIG: Configuration in progress, ignoring command");
            return;
        }
        
        configInProgress = true; // Lock configuration
        
        String arduinoString = pCharacteristic->getValue();
        std::string value(arduinoString.c_str(), arduinoString.length());
        
        if (value.length() > 0) {
            uint8_t cmd = value[0];
            
            switch (cmd) {
                case CMD_SET_GRAVITY:
                    if (value.length() >= 2) {
                        removeGravity = value[1] > 0;
                        Serial.print("Gravity removal set to: ");
                        Serial.println(removeGravity ? "ON" : "OFF");
                        
                        // Send acknowledgment back
                        uint8_t ack[2] = {CMD_SET_GRAVITY, removeGravity};
                        pCharacteristic->setValue(ack, 2);
                        pCharacteristic->notify();
                    }
                    break;
                    
                case CMD_SET_DATA_RATE:
                    if (value.length() >= 2) {
                        int newRate = value[1];
                        if (newRate >= 10 && newRate <= 100) {
                            dataRate = newRate;
                            imuRate = newRate; // Keep IMU rate synced
                            Serial.print("Data rate set to: ");
                            Serial.print(dataRate);
                            Serial.println(" Hz");
                            
                            // Send acknowledgment
                            uint8_t ack[2] = {CMD_SET_DATA_RATE, (uint8_t)dataRate};
                            pCharacteristic->setValue(ack, 2);
                            pCharacteristic->notify();
                        }
                    }
                    break;
                    
                case CMD_SET_SLEEP_TIMEOUT:
                    if (value.length() >= 2) {
                        int timeoutSec = value[1];
                        if (timeoutSec >= 5 && timeoutSec <= 255) {
                            bleInactivityTimeout = timeoutSec * 1000;
                            // Reset motion timer now that system is safely initialized
                            lastMotionTime = millis();
                            Serial.print("Sleep timeout set to: ");
                            Serial.print(timeoutSec);
                            Serial.println(" seconds (motion timer reset)");
                            
                            // Send acknowledgment
                            uint8_t ack[2] = {CMD_SET_SLEEP_TIMEOUT, (uint8_t)timeoutSec};
                            pCharacteristic->setValue(ack, 2);
                            pCharacteristic->notify();
                        }
                    }
                    break;
                    
                case CMD_GET_CONFIG:
                    // Send current configuration
                    uint8_t config[5] = {
                        CMD_GET_CONFIG,
                        removeGravity,
                        (uint8_t)dataRate,
                        (uint8_t)(bleInactivityTimeout / 1000),
                        0  // Reserved for future use
                    };
                    pCharacteristic->setValue(config, 5);
                    pCharacteristic->notify();
                    Serial.println("Configuration sent to client");
                    break;
            }
        }
        
        configInProgress = false; // Unlock configuration
    }
};

class MyServerCallbacks: public BLEServerCallbacks {
    void onConnect(BLEServer* pServer) {
      deviceConnected = true;
      Serial.println("Computer GUI Connected");
    };

    void onDisconnect(BLEServer* pServer) {
      deviceConnected = false;
      Serial.println("Computer GUI Disconnected - will restart advertising");
    }
};

// Function to check if there's significant motion by comparing acceleration changes
bool checkMotionActivity() {
    float ax, ay, az;
    myCodeCell.Motion_AccelerometerRead(ax, ay, az);
    
    if (!motionBaselineSet) {
        // Set initial baseline
        lastAx = ax;
        lastAy = ay;
        lastAz = az;
        motionBaselineSet = true;
        Serial.printf("Motion baseline set: [%.3f, %.3f, %.3f]\n", ax, ay, az);
        return false; // No motion on first reading
    }
    
    // Calculate change in acceleration from previous reading
    float deltaAx = fabsf(ax - lastAx);
    float deltaAy = fabsf(ay - lastAy);
    float deltaAz = fabsf(az - lastAz);
    float totalDelta = sqrt(deltaAx*deltaAx + deltaAy*deltaAy + deltaAz*deltaAz);
    
    Serial.printf("Motion delta: %.3f g (threshold: %.3f)\n", totalDelta, motionThreshold);
    
    // Update baseline for next comparison
    lastAx = ax;
    lastAy = ay;
    lastAz = az;
    
    if (totalDelta > motionThreshold) {
        consecutiveMotionCount++;
        Serial.printf("Motion detected! (consecutive: %d/%d)\n", consecutiveMotionCount, consecutiveMotionRequired);
        
        if (consecutiveMotionCount >= consecutiveMotionRequired) {
            lastMotionTime = millis();
            return true;
        }
    } else {
        consecutiveMotionCount = 0; // Reset counter if no motion
    }
    return false;
}
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
void loop() {
    // Multi-tier power management
    unsigned long currentTime = millis();
    
    // Check USB power status every 5 seconds
    if (currentTime - lastPowerCheck > 5000) {
        lastPowerCheck = currentTime;
        int powerState = myCodeCell.PowerStateRead();
        isUsbPowered = (powerState == 1); // 1 = Running from USB Power
        
        if (isUsbPowered) {
            Serial.println("USB powered - maintaining 60Hz operation");
        }
    }
    
    if (currentTime - lastBleCheck > 1000) { // Check every second
        lastBleCheck = currentTime;
        unsigned long timeSinceMotion = currentTime - lastMotionTime;
        
        // Skip power management if USB powered - stay at full performance
        if (isUsbPowered) {
            // Ensure we're in ACTIVE state when USB powered
            if (currentPowerState != ACTIVE) {
                Serial.println("USB detected - returning to ACTIVE state");
                setCpuFrequencyMhz(160); // Restore full speed
                dataRate = 60; // Restore full data rate
                imuRate = 60; // Restore full IMU rate
                bleActive = true;
                if (!pServer->getAdvertising()->isAdvertising()) {
                    pServer->getAdvertising()->start();
                }
                currentPowerState = ACTIVE;
            }
            // Skip the power management state machine when USB powered
        } else {
            // State machine for power management (battery only)
            switch (currentPowerState) {
            case ACTIVE:
                if (!ota_active && timeSinceMotion > bleInactivityTimeout) {
                    Serial.printf("Entering BLE_OFF state (1Hz mode) after %lums\n", timeSinceMotion);
                    dataRate = lowPowerDataRate; // Reduce to 1Hz transmission
                    imuRate = lowPowerImuRate; // Reduce IMU polling to 10Hz
                    bleActive = false; // Actually turn off BLE notifications
                    pServer->getAdvertising()->stop(); // Stop advertising
                    Serial.println("BLE_OFF: BLE disabled, IMU polling at 10Hz");
                    currentPowerState = BLE_OFF;
                }
                break;
                
            case BLE_OFF:
                if (timeSinceMotion < 500) {
                    Serial.printf("Motion detected - returning to ACTIVE state\n");
                    dataRate = 60; // Restore full data rate
                    imuRate = 60; // Restore full IMU rate
                    bleActive = true; // Re-enable BLE
                    pServer->getAdvertising()->start(); // Restart advertising
                    currentPowerState = ACTIVE;
                } else if (!ota_active && timeSinceMotion > lightSleepTimeout) {
                    Serial.printf("Entering LIGHT_SLEEP state after %lums\n", timeSinceMotion);
                    Serial.println("LIGHT_SLEEP: Sensors active, CPU reduced to 80MHz, BLE off, IMU at 5Hz");
                    imuRate = 5; // Reduce to 5Hz for maximum power savings in light sleep
                    currentPowerState = LIGHT_SLEEP;
                    // Keep sensors running, just reduce CPU frequency
                    setCpuFrequencyMhz(80); // Reduce from 160MHz to 80MHz
                }
                break;
                
            case LIGHT_SLEEP:
                if (timeSinceMotion < 500) {
                    Serial.printf("Motion detected - waking to ACTIVE state\n");
                    setCpuFrequencyMhz(160); // Restore full speed
                    dataRate = 60; // Restore full data rate
                    imuRate = 60; // Restore full IMU rate
                    bleActive = true;
                    currentPowerState = ACTIVE;
                }
                // Stay in light sleep - no deeper sleep mode available due to sensor issues
                break;
            }
        }
    }
    
    // Run sensor readings - deep sleep removed due to BNO085 compatibility issues
    
    if (myCodeCell.Run(imuRate)) {
        // Read quaternion data directly from BNO085 (no gimbal lock!)
        float qr, qi, qj, qk;
        myCodeCell.Motion_RotationVectorRead(qr, qi, qj, qk);
        
        // Read accelerometer and gyro data
        float ax, ay, az;
        float gx, gy, gz;
        
        // Use configured gravity removal setting
        if (removeGravity) {
            // Use linear acceleration (gravity already removed by sensor fusion)
            myCodeCell.Motion_LinearAccRead(ax, ay, az);
        } else {
            // Use raw accelerometer (includes gravity)
            myCodeCell.Motion_AccelerometerRead(ax, ay, az);
        }
        
        myCodeCell.Motion_GyroRead(gx, gy, gz);

        // Check for motion activity to reset sleep timer using delta method
        float totalDelta = 0.0;
        if (motionBaselineSet) {
            float deltaAx = fabsf(ax - lastAx);
            float deltaAy = fabsf(ay - lastAy);
            float deltaAz = fabsf(az - lastAz);
            totalDelta = sqrt(deltaAx*deltaAx + deltaAy*deltaAy + deltaAz*deltaAz);
            
            if (totalDelta > motionThreshold) {
                lastMotionTime = currentTime;
                lastDetectedDelta = totalDelta;
                consecutiveMotionCount++;
            } else {
                consecutiveMotionCount = 0;
            }
            
            // Update baseline for next comparison
            lastAx = ax;
            lastAy = ay;
            lastAz = az;
        } else {
            // Set initial baseline during first loop iteration
            lastAx = ax;
            lastAy = ay;
            lastAz = az;
            motionBaselineSet = true;
            lastMotionTime = currentTime; // Start with motion detected
        }

        // Debug: Show raw accelerometer values and calculated motion
        const char* stateNames[] = {"ACTIVE", "BLE_OFF", "LIGHT_SLEEP", "DEEP_SLEEP"};
        Serial.printf("Raw accel: [%.3f, %.3f, %.3f] | Delta: %.4f | Threshold: %.3f | BLE: %s | State: %s | ", 
                     ax, ay, az, totalDelta, motionThreshold, bleActive ? "ON" : "OFF", stateNames[currentPowerState]);

        // Read battery level
        int batteryLevel = myCodeCell.BatteryLevelRead();
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

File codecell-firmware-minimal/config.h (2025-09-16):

#ifndef CONFIG_H
#define CONFIG_H

// Device Configuration
#define DEVICE_NAME         "FitChip011"

// BLE Service UUIDs - Single Service with Quaternion + OTA Control
#define SERVICE_UUID        "12345678-1234-1234-1234-123456789012"
#define CHARACTERISTIC_UUID "dcba4330-dcba-4321-dcba-432123456791"
#define OTA_CONTROL_CHAR_UUID "8f20d6c8-5f7d-4e7b-9b1c-0a701c3a0002"

// Sensor Performance Configuration
#define UPDATE_RATE         60    // Hz - optimized for 60Hz performance
#define SLEEP_TIMEOUT       10000 // ms - sleep after 10 seconds of no motion

// Motion Detection Configuration
#define MOTION_THRESHOLD    0.3f  // g-force threshold for motion detection

// Performance-Critical Sensor Configuration
// This exact combination achieves 60Hz accel/gyro + 20-40Hz quaternions
#define SENSOR_CONFIG (MOTION_ACCELEROMETER + MOTION_GYRO + MOTION_ROTATION + MOTION_MAGNETOMETER)

// Timing Configuration (Performance Critical)
#define SENSOR_STABILIZATION_MS  3000  // Initialization delay
#define MAIN_LOOP_DELAY_MS       1     // Minimal cooperative delay
#define DEBUG_INTERVAL_MS        1000  // 1-second debug output

// OTA Worker Configuration (Conservative Settings)
#define OTA_CHUNK_SIZE          128     // Conservative chunk size (bytes)
#define OTA_QUEUE_SIZE          8       // FreeRTOS queue depth
#define OTA_TASK_STACK_SIZE     4096    // Stack size for OTA worker task
#define OTA_TASK_PRIORITY       1       // Low priority (below main loop)
#define OTA_CHUNK_TIMEOUT_MS    30000   // 30-second chunk timeout
#define OTA_SESSION_TIMEOUT_MS  300000  // 5-minute session timeout

#endif // CONFIG_H

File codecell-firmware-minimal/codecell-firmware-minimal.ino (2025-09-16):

/*
 * CodeCell Minimal Motion Detection Firmware - Phase 4
 * Performance-optimized modular architecture
 *
 * Achieved performance: A:60Hz G:60Hz Q:20-40Hz BLE:60Hz
 * Maintains vendor patterns while enabling clean module structure
 */

#include "config.h"
#include "imu_manager.h"
#include "ota_worker.h"
#include <CodeCell.h>
#include <BLEDevice.h>
#include <BLEServer.h>
#include <BLEUtils.h>
#include <BLE2902.h>
#include <esp_ota_ops.h>

CodeCell myCodeCell;
ImuManager imuManager;
OtaWorker otaWorker;

// Debug counters for rate monitoring
static unsigned long blePacketsSent = 0;
static unsigned long lastDebugTime = 0;

// BLE state
BLEServer* pServer = NULL;
BLECharacteristic* pCharacteristic = NULL;
BLECharacteristic* pOtaControlChar = NULL;
bool deviceConnected = false;
bool oldDeviceConnected = false;

// LED for visual feedback - use CodeCell's LED_PIN (already defined in library)
// const int LED_PIN = LED_BUILTIN;  // Removed - LED_PIN already defined by CodeCell library

// Simple BLE callbacks - no heavy work in callbacks!
class MyServerCallbacks: public BLEServerCallbacks {
    void onConnect(BLEServer* pServer) {
      deviceConnected = true;
      Serial.println("BLE Client Connected");
    };

    void onDisconnect(BLEServer* pServer) {
      deviceConnected = false;
      Serial.println("BLE Client Disconnected");
    }
};

// OTA Control Characteristic Callback
class OtaControlCharCallbacks: public BLECharacteristicCallbacks {
    void onWrite(BLECharacteristic* pCharacteristic) override {
        String value = pCharacteristic->getValue();

        if (value.length() > 0) {
            const uint8_t* data = (const uint8_t*)value.c_str();
            uint16_t length = value.length();

            Serial.printf("OTA Control: Received %d bytes, command: 0x%02x", length, data[0]);
            // Print hex dump for debugging
            Serial.print(" [");
            for (int i = 0; i < length && i < 16; i++) {
                Serial.printf("%02x", data[i]);
                if (i < length - 1 && i < 15) Serial.print(" ");
            }
            if (length > 16) Serial.print("...");
            Serial.println("]");

            if (length >= 1) {
                uint8_t command = data[0];

                switch (command) {
                    case 0x01: { // OP_START - [0x01][length:4][crc32:4][chunk_size:2] (11 bytes total, little-endian)
                        if (length >= 11) {
                            // Parse little-endian fields
                            uint32_t totalSize = data[1] | (data[2] << 8) | (data[3] << 16) | (data[4] << 24);
                            uint32_t expectedCrc32 = data[5] | (data[6] << 8) | (data[7] << 16) | (data[8] << 24);
                            uint16_t requestedChunkSize = data[9] | (data[10] << 8);

                            Serial.printf("OTA: START command - Size: %u, CRC32: 0x%08x, Chunk: %u\n",
                                         totalSize, expectedCrc32, requestedChunkSize);

                            if (otaWorker.startOta(totalSize)) {
                                // Send immediate ACK: [0xa1]
                                uint8_t ack_response = 0xa1;
                                pOtaControlChar->setValue(&ack_response, 1);
                                pOtaControlChar->notify();
                                Serial.println("OTA: Sent START ACK: 0xa1");
                            } else {
                                uint8_t error_response = 0xff;
                                pOtaControlChar->setValue(&error_response, 1);
                                pOtaControlChar->notify();
                                Serial.println("OTA: Sent START ERROR: 0xff");
                            }
                        } else {
                            Serial.printf("OTA: START command too short (%d bytes, expected 11)\n", length);
                            uint8_t error_response = 0xff;
                            pOtaControlChar->setValue(&error_response, 1);
                            pOtaControlChar->notify();
                        }
                        break;
                    }

                    case 0x02: { // OP_DATA - [0x02][offset:4][data...] (little-endian)
                        if (length >= 5) {
                            uint32_t offset = data[1] | (data[2] << 8) | (data[3] << 16) | (data[4] << 24);
                            uint16_t dataLength = length - 5;
                            const uint8_t* chunkData = &data[5];

                            Serial.printf("OTA Data: Offset %u, Length %u\n", offset, dataLength);

                            if (otaWorker.queueChunk(chunkData, dataLength, offset, false)) {
                                Serial.printf("OTA Data: Chunk at offset %u queued successfully\n", offset);
                            } else {
                                Serial.printf("OTA Data: Failed to queue chunk at offset %u\n", offset);
                            }
                        } else {
                            Serial.printf("OTA: DATA command too short (%d bytes, expected >=5)\n", length);
                        }
                        break;
                    }

                    case 0x03: { // OP_FINISH - [0x03]
                        Serial.println("OTA: FINISH command received");

                        uint8_t finish_ack = 0xa2;
                        pOtaControlChar->setValue(&finish_ack, 1);
                        pOtaControlChar->notify();
                        Serial.println("OTA: Sent FINISH ACK: 0xa2");
                        break;
                    }

                    default: {
                        Serial.printf("OTA: Unknown command: 0x%02x\n", command);
                        uint8_t unknown_response = 0xff;
                        pOtaControlChar->setValue(&unknown_response, 1);
                        pOtaControlChar->notify();
                        break;
                    }
                }
            }
        }
    }
};
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

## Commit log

2025-07-29 Initial firmware commit with battery monitoring
    - ESP32 firmware for CodeCell with BLE communication
    - 50Hz IMU data streaming (roll, pitch, yaw, accel, gyro)
    - Battery level monitoring with LED indicators
    - Auto-reconnect BLE functionality
    - 30-second battery reading interval
2025-07-30 Implement 50Hz battery reading for immediate responsiveness
    - Read battery every cycle with IMU data instead of every 30 seconds
    - Immediate feedback when plugging/unplugging charger
    - Smooth battery level updates with no delays
    - Minimal power impact (ADC ~10μs vs BLE ~200ms)
    - Simplified code by removing caching and timer logic
    Closes #4
2025-07-30 Fix Arduino IDE folder structure - move .ino into matching folder name
    Arduino IDE requires .ino files to be in a folder with the same name.
    Moved codecell-firmware.ino into codecell-firmware/ directory.
    [codecell-firmware.ino]
2025-07-30 Optimize battery life by reducing BLE polling rate to 24Hz
    - Changed dataRate from 50Hz to 24Hz
    - Reduces BLE transmission frequency by ~50%
    - Maintains smooth motion tracking for gaming
    - Significantly extends battery life
    24Hz is sufficient for controller input (many commercial controllers use 30Hz or less).
    Fixes #7
    [codecell-firmware.ino]
2025-07-30 Implement compact binary protocol for BLE data transmission
    - Replace text protocol (~85 bytes) with binary protocol (19 bytes) = 77% reduction
    - Comprehensive documentation of encoding/decoding process
    - Optimized scaling factors for gaming controller use:
    * Rotation: ±327° range, 0.01° precision
    * Acceleration: ±65.5g range, 0.002g precision (increased for vigorous motion)
    * Gyroscope: ±3276°/s range, 0.1°/s precision
    * Battery: 0-255 direct mapping
    - Little-endian byte order for web compatibility
    - Significant battery life improvement from reduced transmission size
    - Maintains excellent precision for all sensor values
    Requires corresponding web app parser update to decode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
    [codecell-firmware.ino]
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2025-08-04 Update README with binary protocol documentation and latest features
    - Document binary protocol format (19 bytes, 77% size reduction)
    - Add detailed byte layout and scaling factors
    - Update data rate to 24Hz (optimized from 50Hz)
    - Add performance optimization section
    - Document known issues (sleep mode, IMU overflow)
    - Add changelog with v2.0.0 features
    - Fix Arduino IDE file path
    - Add protocol auto-detection information
2025-08-04 Add comprehensive Bill of Materials (BOM) section to README
    - Document CodeCell Light + Motion variant with 170mAh battery
    - Add detailed specifications for all components
    - Include SPDT slide switch with full dimensions
    - List JST 1.25mm connectors for battery connection
    - Document M1.2 mounting hardware requirements
    - Add assembly notes and total weight calculation
    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
2025-08-04 Add 3D printable enclosure files and safety requirements
    - Add enclosure/ directory with 3D print files:
    * Up V7 Body - PC-FR Rev 2 (main controller body)
    * Up V7 lid - PC-FRrev2 (top cover)
    * Up V7 switch cradle - PC-FR Rev 3 (power switch mount)
    - Require fire retardant (PC-FR) materials for production use
    - Add LiPo safety bag to BOM for safe storage/charging
    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
    [Up V7 Body - PC-FR Rev 2.obj, Up V7 lid - PC-FRrev2.obj, Up V7 switch cradle - PC-FR Rev 3.obj]
2025-08-04 Add quick order BOM table and required tools list
    - Create concise procurement table for one FitChip assembly
    - Add required tools and materials section
    - Include Bambu Lab PC-FR fire retardant filament link
    - List essential assembly tools: soldering iron, heat gun, tweezers
    - Specify heat shrink tubing and 3D printer requirements
    - Organize for easy ordering and project planning
2025-08-04 Clean up merge conflict and finalize BOM documentation
    - Remove erroneous feature branch comment from Configuration section
    - Maintain comprehensive BOM with quick order table and required tools
    - Ready for sleep mode implementation
2025-08-05 Fix Arduino IDE setup instructions
    - Remove ESP32 from Library Manager section (incorrect)
    - ESP32 core is installed via Boards Manager, not Library Manager
    - Add clarifying note about BLE support being included with ESP32 core
    - Resolves confusion where users can't find ESP32 in Library Manager
2025-08-06 Change Bluetooth device name from CodeCell to FitChip
    - Updated BLEDevice::init() to use 'FitChip' as the device name
    - This is the name that appears when scanning for Bluetooth devices
    - Requested by team for better branding
2025-08-19 Rename enclosure folder to enclosure_3D_models
    [Up V7 Body - PC-FR Rev 2.obj, Up V7 lid - PC-FRrev2.obj, Up V7 switch cradle - PC-FR Rev 3.obj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]
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2025-08-19 Update enclosure README with V9 files, detailed print settings, and assembly instructions
2025-09-02 Replace CodeCell firmware with minimal quaternion version
    Switched from full 20-byte quaternion protocol to minimal 19-byte version
    that sends only X,Y,Z components with W calculated on the web app side.
    This maintains the same packet size as the original Euler protocol for
    maximum battery efficiency while eliminating gimbal lock issues.
    [codecell-firmware.ino, proximity-sleep.ino, serial-test.ino]
2025-09-05 Implement tiered power management system for motion-based sleep
    - Add 3-tier power states: ACTIVE (60Hz IMU + 60Hz BLE) -> BLE_OFF (10Hz IMU + 1Hz BLE) -> LIGHT_SLEEP (5Hz IMU + BLE off + 80MHz CPU)
    - Remove deep sleep due to BNO085 sensor compatibility issues
    - Implement variable IMU polling rates for power optimization
    - Maintain motion detection responsiveness across all power states
    - Power transitions: 10s inactivity -> BLE_OFF, 1min -> LIGHT_SLEEP
    - Preserve sensor functionality while maximizing battery efficiency
    [codecell-firmware-sleep.ino, codecell-firmware.ino, serial-test.ino]
2025-09-08 Implement gravity removal toggle for accelerometer readings
    - Add removeGravity flag to control gravity compensation (default: true)
    - Initialize LINEAR_ACC and GRAVITY sensors for BNO085 sensor fusion
    - Switch between Motion_LinearAccRead() (gravity-free) and Motion_AccelerometerRead() (raw)
    - Update protocol documentation to indicate gravity removal status
    - Leverages BNO085's built-in sensor fusion for accurate gravity separation
2025-09-08 Add BLE configuration system for live parameter tweaking
    Features:
    - New writable BLE characteristic for configuration (UUID: ..6792)
    - Command-based protocol for parameter updates
    - Configurable gravity removal toggle (CMD_SET_GRAVITY: 0x01)
    - Dynamic data rate adjustment 10-100Hz (CMD_SET_DATA_RATE: 0x02)
    - Configuration query support (CMD_GET_CONFIG: 0x03)
    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
2025-09-08 Add BLE configuration and gravity removal to sleep firmware
    Features added to the advanced sleep firmware with OTA support:
    - BLE configuration characteristic for live parameter tweaking
    - Configurable gravity removal (CMD_SET_GRAVITY: 0x01)
    - Adjustable sleep timeout (CMD_SET_SLEEP_TIMEOUT: 0x03)
    - Configuration query support (CMD_GET_CONFIG: 0x04)
    - Initialize LINEAR_ACC and GRAVITY sensors for proper gravity separation
    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
2025-09-08 Fix compilation error: Arduino String to std::string conversion
    The BLE library returns Arduino String, not std::string.
    Fixed by properly converting String to std::string using c_str() and length().
    This matches the pattern used in other callback classes (OtaControlCallbacks, OtaDataCallbacks).
    [codecell-firmware-sleep.ino]
2025-09-08 Add safety flags for configuration during initialization
    - Added systemInitialized flag to prevent config during startup
    - Added configInProgress flag to prevent concurrent config operations
    - Re-added motion timer reset for sleep timeout, but only after safe initialization
    - Prevents BLE configuration from interfering with sensor setup
    [codecell-firmware.ino, qc-codecell-firmware.ino, qc-test-firmware.ino]
2025-09-16 Add production-ready CodeCell firmware with modular architecture and OTA support
    🎯 PRODUCTION-READY FIRMWARE
    - Single BLE service with 60Hz quaternion streaming
    - Verified performance: A:60Hz G:60Hz Q:20-40Hz BLE:60Hz
    - Real battery status reporting (101=charging, 102=USB only)
    - Motion detection with configurable threshold
    - Vendor-compliant sleep/wake patterns
    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
2025-09-16 Archive old firmware experiments and update README for production deployment
    📁 REPOSITORY CLEANUP
    - Moved all experimental firmware to archive/old-firmware-experiments/
    - Archived troubleshooting docs to archive/
    - Clean repository structure with clear production firmware location
    📖 UPDATED README
    - Points to codecell-firmware-minimal/ as main production firmware
    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
2025-09-16 Complete OTA integration with single-service architecture and quaternion W sign fix
    🔧 FIXES COMPILATION ISSUES
    - Added missing OTA constants to config.h (OTA_CHUNK_SIZE, OTA_QUEUE_SIZE, etc.)
    - Fixed quaternion W sign ambiguity by packing sign into battery byte bit 7
    - Preserved battery values 0-127 with special values 101 (charging), 102 (USB only)
    🚀 SINGLE-SERVICE OTA ARCHITECTURE
    - Added OTA characteristics to existing data service (not separate service)
    - Maintains working 60Hz quaternion streaming
    - Service: 12345678-1234-1234-1234-123456789012
    - Quaternion: dcba4330-dcba-4321-dcba-432123456791 (NOTIFY)
    - OTA Control: 8f20d6c8-5f7d-4e7b-9b1c-0a701c3a0002 (WRITE/NOTIFY)
    - OT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
    [codecell-firmware-minimal.ino, config.h]
2025-09-16 Fix OTA protocol mismatch and add comprehensive partition debugging
    Major fixes to resolve web app 0xa1 timeout error:
    **Protocol Fixes:**
    - Remove separate OTA_DATA characteristic, use single OTA_CONTROL for all commands
    - Fix START command parsing: 11-byte format with little-endian fields
    - Add DATA command handling: offset-based chunks via same characteristic
    - Update OTA worker for offset-based writes instead of sequential chunks
    - Add immediate ACK responses (0xa1 for START, 0xa2 for FINISH)
    **Debugging Enhancements:**
    - Add comprehensive partition size logging to identify OTA space limits
    - Enhanced error reporting with Update.errorString() details
    - Hex dump logging of all received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
    [codecell-firmware-minimal.ino, config.h, ota_worker.cpp]
